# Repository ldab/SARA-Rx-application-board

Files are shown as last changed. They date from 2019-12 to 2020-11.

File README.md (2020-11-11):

# SARA-Rx application board

 SARA-R4 NB-IoT + Cat-M1 + GNSS application board - NINA-B3 with Secure MQTT






# **:heavy_exclamation_mark:BEFORE YOU DO ANYTHING, CHECK BATTERY POLARITY:heavy_exclamation_mark:**

## TODO

- [ ] More details about battery etc...
- [ ] !!! Better Socket close URC handler.
- [ ] Check AT response based on the last chars, in order to avoid missing URCs when after "OK" for example
- [ ] Implement Subscribe;

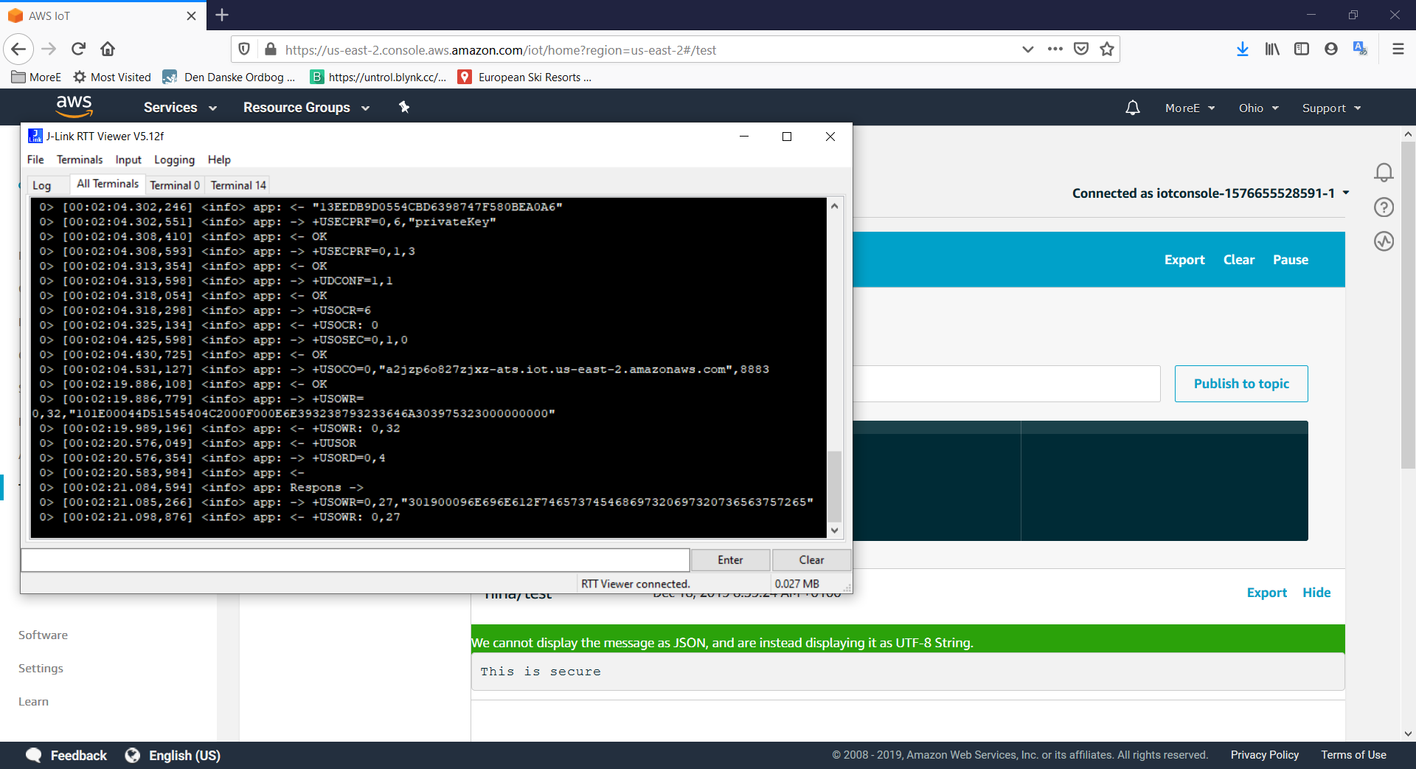
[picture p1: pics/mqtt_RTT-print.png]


## Energy Budget

* 88mA active current;
* Code takes ~10 seconds to execute;
* Wakes every hour;
* 40uA Sleep current;
* 10 hours of light available;
* V charge ready = 3.67V;
* V Over discharge = 3.6V;
* V Over charge = 4.12V;

**Source Power Required = 3.8mW**

**Storage Required = 4.73mAh**

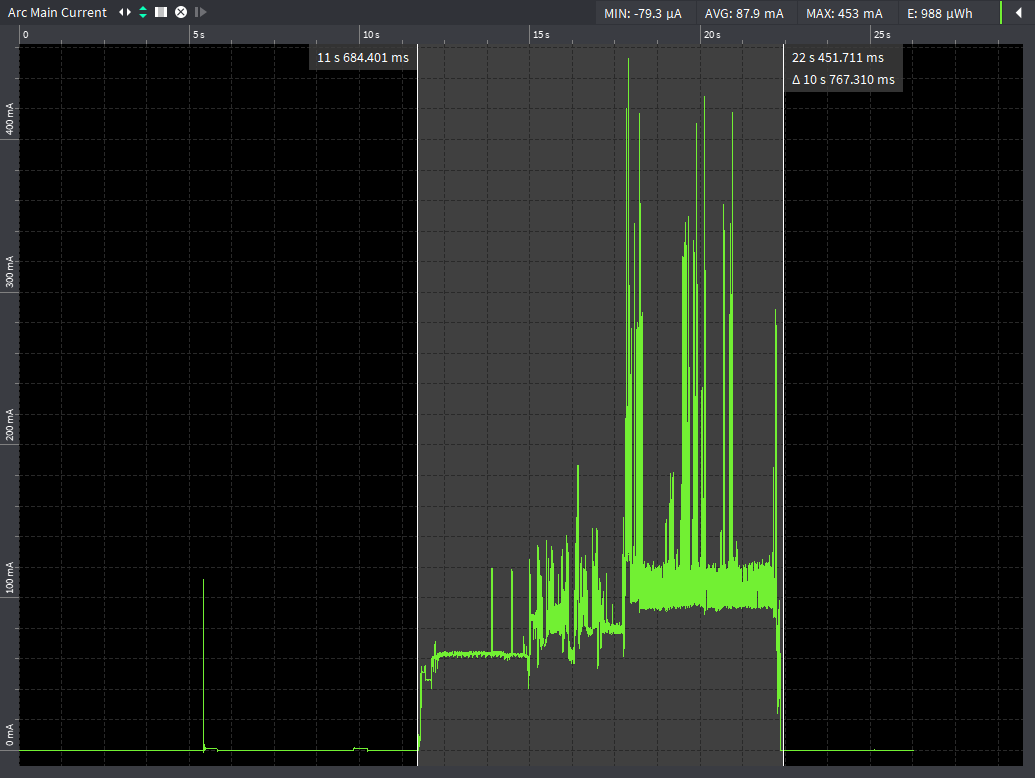
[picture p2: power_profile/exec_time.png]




### Sleep Current

| Component 	| Current 	|
|---	|---	|
| SARA-R410 	| 7uA 	|
| NINA-B3 	| 3uA 	|
| Batt ADC  	| 3uA 	|
| SHTC3 	| 0.5uA 	|
| TP4054 	| 1uA 	|
| TXS0108 	| 5uA(?)  	|
| TPS61021A  	| 17uA 	  |
| TOTAL 	| ~37uA 	|

## Nordic SDK

* This is based on nRF5_SDK_16.0.0_98a08e2, get yours here: https://www.nordicsemi.com/Software-and-tools/Software/nRF5-SDK/Download



1. Sign in to the AWS IoT Console
2. Register a Device in the Registry
3. Configure Your Device
4. View Device MQTT Messages with the AWS IoT MQTT Client

https://docs.aws.amazon.com/iot/latest/developerguide/iot-gs.html

* 120mA active current;
* Code takes 15 seconds to execute;
* Wakes every hour;
* 2mA Sleep current *This needs to be optimized*;
* 10 hours of light available;
* V charge ready = 3.67V;
* V Over discharge = 3.6V;
* V Over charge = 4.12V;

1. Clone this repo to a local folder ```> git clone https://github.com/ldab/SARA-Rx-application-board```
2. Point the `$(SDK)` @`./code/ninab3/blank/ses/libuarte_pca10056.emProject` to where you have installed Nordic SDK, for example `C:\nRF\nRF5_SDK_16.0.0_98a08e2`
3. Like so: `macros="CMSIS_CONFIG_TOOL=C:/nRF/nRF5_SDK_16.0.0_98a08e2/external_tools/cmsisconfig/CMSIS_Configuration_Wizard.jar;SDK=C:/nRF/nRF5_SDK_16.0.0_98a08e2"`
4. Open the SEGGER Embedded Studio project file located in `./code/ninab3/blank/ses/libuarte_pca10056.emProject`

* PS. don't forget to set the NFC Pins as GPIO on the Preprocessor: `CONFIG_NFCT_PINS_AS_GPIOS`

Ref. https://devzone.nordicsemi.com/f/nordic-q-a/44638/how-to-move-an-sdk-example-out-of-the-sdk-tree

## IoT Dashboard

* Adafruit https://io.adafruit.com provides a free MQTT broker with a Dashboard allowing this project to be displayed publicly with little to no effort
  * Create an account and insert your KEY as the `MQTT_PASS`
  * `MQTT_USER` is the username used for creating the account.

* Adafruit expect data as a json, for example:

    ```
    sprintf(_msg, "{\"feeds\": {\"T\": %.01f,\"H\": %.01f,\"Bpc\": %d,\"RSRP\": %.02f,\"Bv\": %.02f}}",
            temperature, humidity, batt_lvl_in_percentage, modemInfo.RSRP, _b)
    ```

* The topic, groups and feeds are created automagically, on the example the MAC address is added as an identifier:

    ```
    sprintf(topic, "lbispo/g/nina_%X/json", NRF_FICR->DEVICEADDR[0]);
    ```

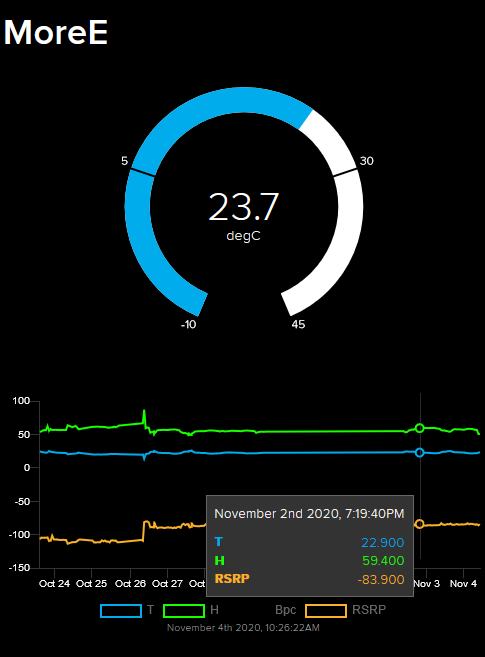
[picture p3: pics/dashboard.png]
 

https://io.adafruit.com/lbispo/dashboards/moree?kiosk=true

## Efficiency

 

## Schematic

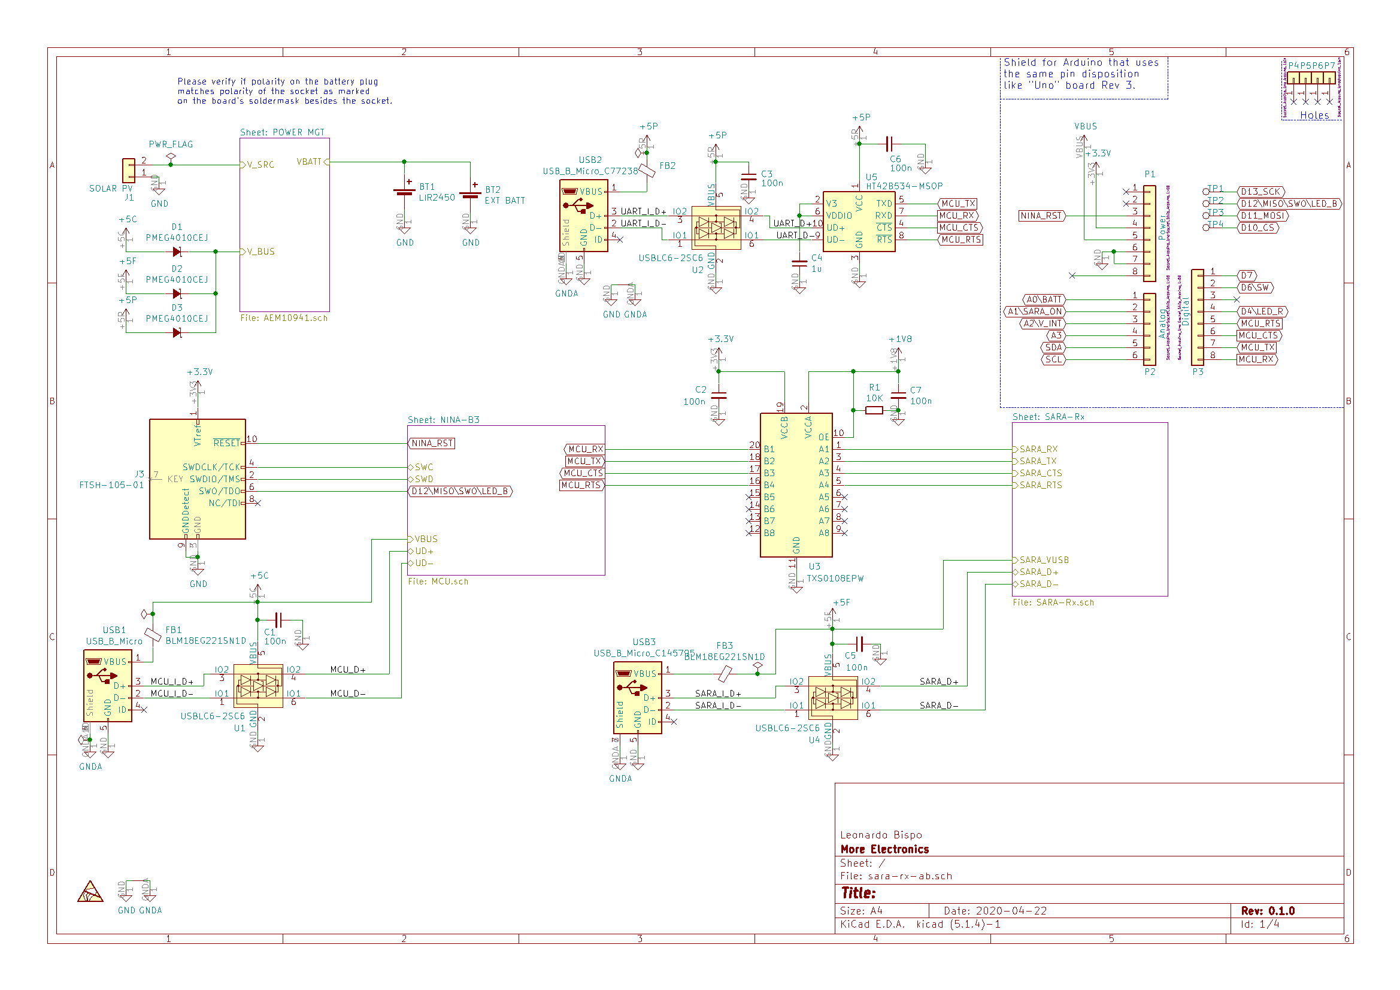
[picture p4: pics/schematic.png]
Board Schematic


## PCB

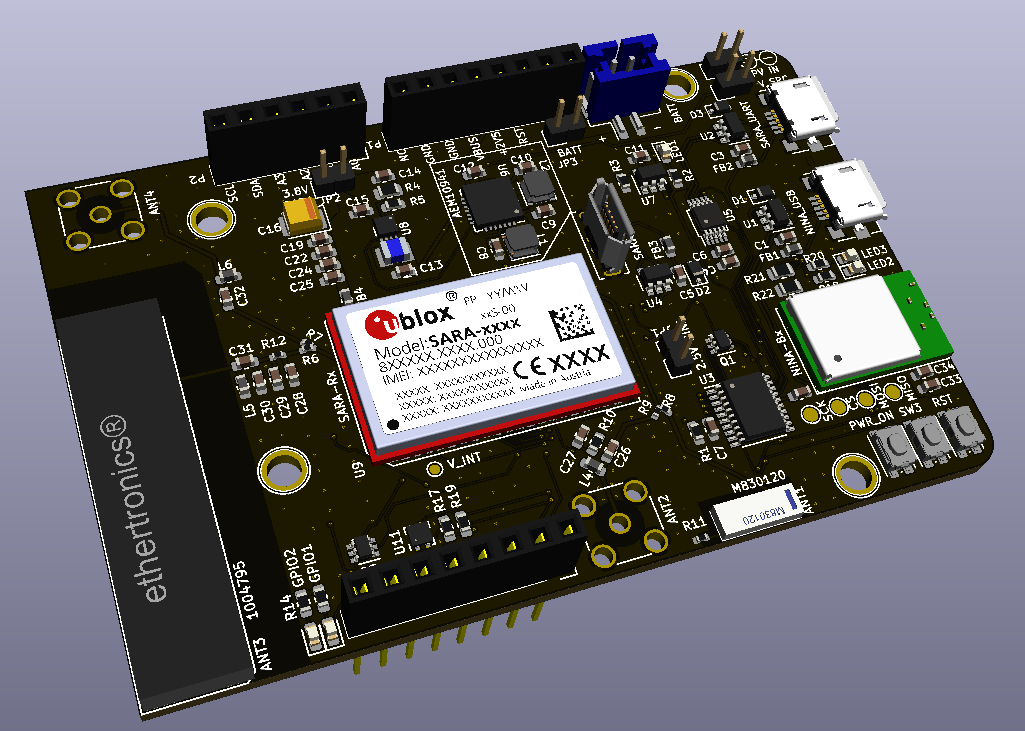
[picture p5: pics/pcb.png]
3D PCB
 

## BOM

Board BOM

## Enclosure

3D 

## Kown issues, limintations

* MQTT Socket Implementaition can only **publish** QoS 0 messages.

## Thoughts or Improvements

* Use STATUS 2 of AEM10941 as last grasp;
* Control boost converter EN, in order to turn SARA Off;
  * Remove boost converter, as it does not boost a lot since Vbatt ON = 3.6V.
* SARA RESET Pin access;
* Use 101b AEM10941 Configuration in order to Vovdis = 3.0V givin extra ~20% battery (?).
* Open Drain 74LVC3G07 buffer on NINA LED, in order to avoid leakage.

## Credits

* [MQTTBox](http://workswithweb.com/mqttbox.html) for Windows in order to communicate with the broker and check messages;
* [CloudMQTT](https://www.cloudmqtt.com/) Free Cloud Broker;
* MQTT implementation inspired and based on [knolleary PubSub Client](https://github.com/knolleary/pubsubclient);
* AT Commands implementation inspired on [vshymanskyy TinyGSM](https://github.com/vshymanskyy/TinyGSM);
* GitHub Shields and Badges created with [Shields.io](https://github.com/badges/shields/);

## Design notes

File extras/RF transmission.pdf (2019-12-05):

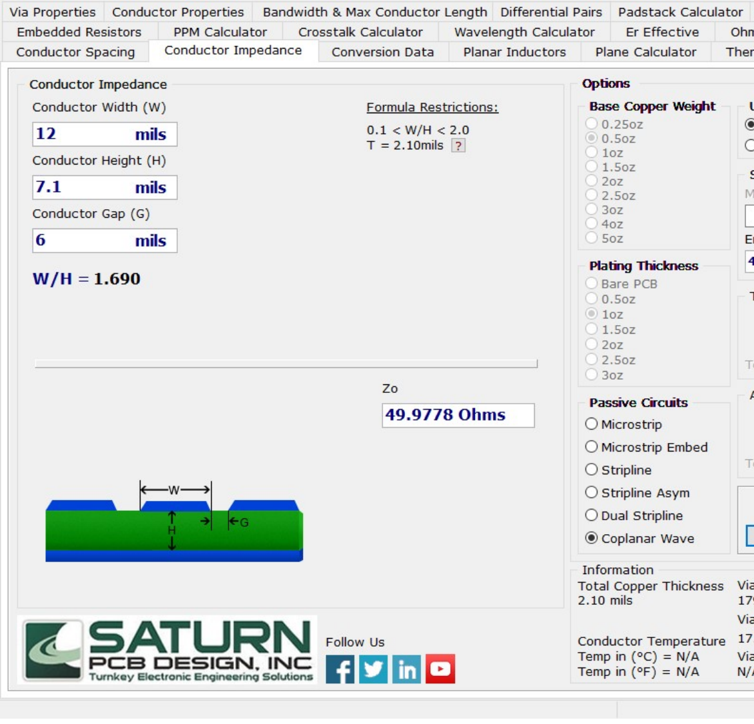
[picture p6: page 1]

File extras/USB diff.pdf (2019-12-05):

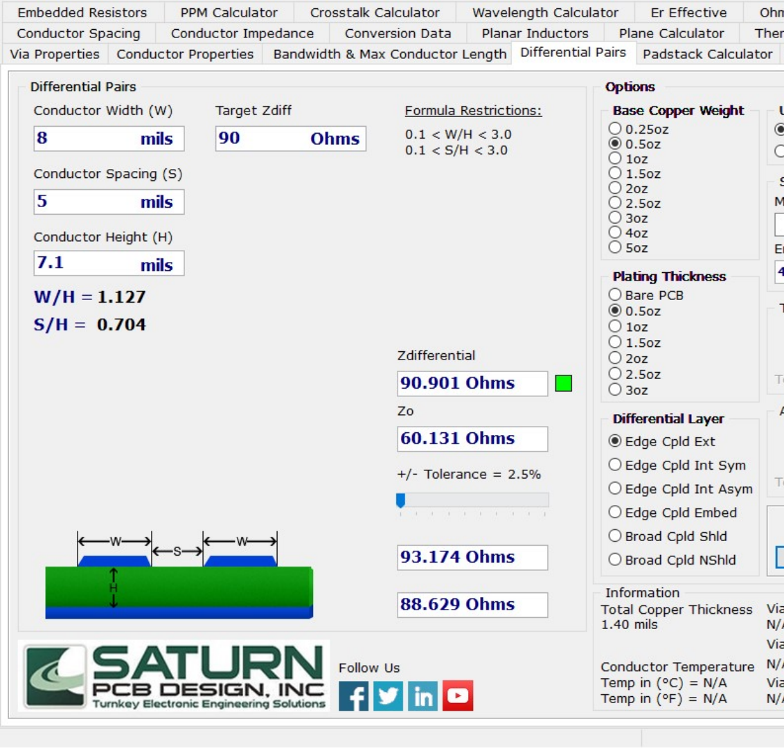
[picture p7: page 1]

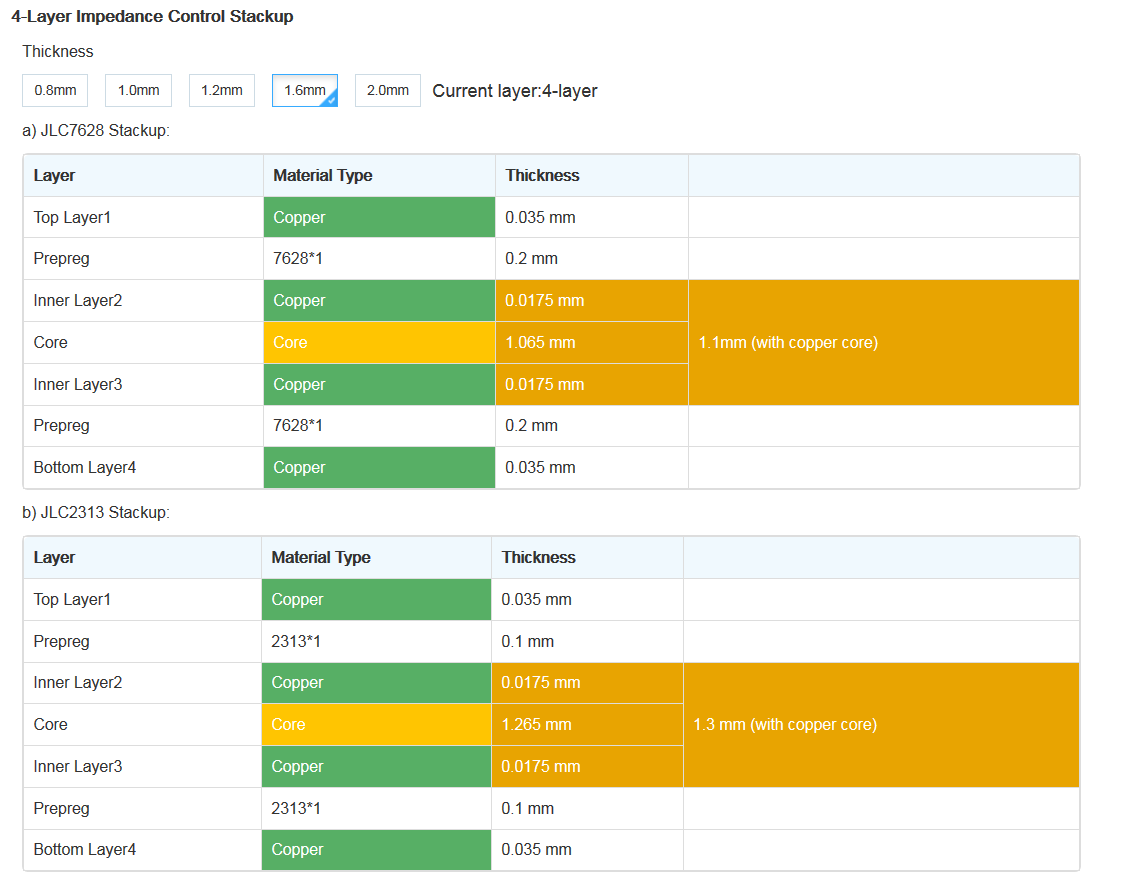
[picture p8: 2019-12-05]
PCB/PCB Stackup.png

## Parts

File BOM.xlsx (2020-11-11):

 | Quantity | Manufacture Part Number | Manufacturer(optional) | Description(optional) | LCSC Part Number(optional) | Package(optional)
ANT2 | 1 |  |  | Conn_Coaxial | C411575 | Connector_Coaxial:SMA_Amphenol_132291_Vertical
BT1 | 1 |  |  | LIR2450 | C238100 | Battery:BatteryHolder_Keystone_3008_1x2450
BT2 | 1 | B2B-PH-SM4-TB(LF)(SN) |  | EXT BATT | C160352 | Connector_JST:JST_PH_B2B-PH-SM4-TB_1x02-1MP_P2.00mm_Vertical
> C1-C3, C5-C7, C19, C23, C33, C34 | 10 | C1608X7R1E104KT000N |  | 100n | C338036 | Capacitor_SMD:C_0603_1608Metric
C4 | 1 | EMK107B7105KA-T |  | 1u | C92759 | Capacitor_SMD:C_0603_1608Metric
> C8-C13, C15 | 7 | JMK107BJ106MA-T |  | 10u | C87152 | Capacitor_SMD:C_0603_1608Metric
> C14, C31 | 2 | CC0603CRNPO9BN4R7 |  | 4.7p | C282071 | Capacitor_SMD:C_0603_1608Metric
C16 | 1 |  |  | 100u | C16133 | Capacitor_Tantalum_SMD:CP_EIA-3528-21_Kemet-B
> C17, C18, C20, C21, C26 | 5 | CC0603JRNPO9BN470 |  | 47p | C1671 | Capacitor_SMD:C_0603_1608Metric | replaced
C25 | 1 | GRM1885C2A680JA01D |  | 68p | C162261 | Capacitor_SMD:C_0603_1608Metric
> C22, C27 | 2 | CC0603KRX7R0BB103 |  | 10n | C107059 | Capacitor_SMD:C_0603_1608Metric
C28 | 1 | GRM1885C1H5R0BA01D |  | 5p | C162236 | Capacitor_SMD:C_0603_1608Metric
C30 | 1 | CL10C0R3CB8NNNC |  | 0.3p | C170140 | Capacitor_SMD:C_0603_1608Metric
> C24, C32 | 2 | CGA3E2C0G1H150JT0Y0N |  | 15p | C342889 | Capacitor_SMD:C_0603_1608Metric
> D1-D3 | 3 | PMEG4010CEJ |  | PMEG4010CEJ | C50704 | Diode_SMD:D_SOD-323F
> D4, D5 | 2 | PESD5V0U2BT |  | PESD5V0U2BT | C85399 | Package_TO_SOT_SMD:SOT-23
> FB1-FB4 | 4 | BLM18EG221SN1D |  | BLM18EG221SN1D | C17305 | Inductor_SMD:L_0603_1608Metric | replaced
J3 | 1 | 20021221-00010C4LF |  | FTSH-105-01 | C180221 | custom:SWD_JTAG
J5 | 1 | SMO-1512 |  | SMO-1512 | C125621 | SMO1512
 | 4 | C5664 |  | Jumper Shunt | C5664
> JP1-JP4 | 4 | MTP220-1102S1 |  | Jumper_NC_Small | C376075 | Connector_PinHeader_2.00mm:PinHeader_1x02_P2.00mm_Vertical
> L1, L2 | 2 | NRH3010T100MNV |  | 10u | C223113 | SamacSys_Parts:L_Taiyo-Yuden_NRH30xx
L3 | 1 | DFE252012P-R47M=P2 |  | DFE252012P-R47M=P2 | C237552 | INDC2520X120N
L4 | 1 | HK160827NJ-T |  | 27n | C222672 | Inductor_SMD:L_0603_1608Metric
L5 | 1 | VHF160808H8N2ST |  | 8.2n | C139273 | Inductor_SMD:L_0603_1608Metric
L6 | 1 | LQG18HN39NJ00D |  | 39n | C86134 | Inductor_SMD:L_0603_1608Metric | replaced
> LED1, LED2 | 2 | 19-217/R6C-AL1M2VY/3T |  | 19-217/R6C-AL1M2VY/3T | C72044 | LED_SMD:LED_0603_1608Metric
LED3 | 3 | LTST-C191KGKT |  | LTST-C191KGKT | C125098 | LED_SMD:LED_0603_1608Metric
> Q1, Q2 | 2 | MUN5214DW1T1G |  | MUN5214DW1T1G | C94403 | Package_TO_SOT_SMD:SOT-363_SC-70-6
> R1, R2, R17, R19,R3,R23 | 6 | 0603WAJ0103T5E |  | 10K | C15401 | Resistor_SMD:R_0603_1608Metric
> R4, R21, R22 | 3 | WF08H1004BTL |  | 1M±0.1% | C384461 | Resistor_SMD:R_0805_2012Metric
R5 | 1 | RC0603FR-07267KL |  | 267K | C185347 | Resistor_SMD:R_0603_1608Metric
R10 | 1 | 0603WAJ0100T5E |  | 10 | C25202 | Resistor_SMD:R_0603_1608Metric
> R6, R8, R11, R12, R15, R16 | 6 | 0402WGF0000TCE |  | 0R | C17168 | Resistor_SMD:R_0402_1005Metric
> R13, R14, R18, R20 | 4 | 0603WAJ0102T5E |  | 1K | C25585 | Resistor_SMD:R_0603_1608Metric
SW1 | 3 | K2-1809SN-D4DW-06 |  | PWR_ON | C128941 | SamacSys_Parts:SW_Push_1P1T_NO_CK_KMR2
U3 | 1 | TXS0108EPWR |  | TXS0108EPWR | C17206 | Package_SO:SSOP-20_4.4x6.5mm_P0.65mm
> U1, U2, U4 | 3 | USBLC6-2SC6 |  | USBLC6-2SC6 | C7519 | Package_TO_SOT_SMD:SOT-23-6
U5 | 1 | HT42B534 |  | HT42B534-MSOP | C95344 | Package_SO:MSOP-10_3x3mm_P0.5mm
U7 | 1 | TP4054 |  | TP4054 | C32574 | Package_TO_SOT_SMD:SOT-23-5
U8 | 1 | TPS61021A |  | TPS61021A | C193037 | Package_SON:WSON-8-1EP_2x2mm_P0.5mm_EP0.9x1.6mm_ThermalVias
U11 | 1 | SHTC3 |  | Temperature & Humidity Sensors | C194656 | Package_DFN_QFN:AMS_QFN-4-1EP_2x2mm_P0.95mm_EP0.7x1.6mm
USB1, USB2 | 2 | U-F-M5SS-W-1 |  | USB_B_Micro | C77238 | SamacSys_Parts:C77238
USB3 | 1 | U-D-M5DD-W-1 |  | USB_B_Micro_C145795 | C145795 | custom:USB_Micro-B_U-D-M5DD-W-1_VERTICAL

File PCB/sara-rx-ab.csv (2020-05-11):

Source: | D:\untrol.io\10. Open Source\SARA-Rx-application-board\PCB\sara-rx-ab.sch
Date: | 01/22/20 14:25:27
Tool: | Eeschema (5.1.4)-1
Generator: | C:\Program Files\KiCad\bin\scripting\plugins/bom_csv_grouped_by_value_with_fp.py
Component Count: | 123
Ref | Qnty | Value | Cmp name | Footprint | Description | Vendor
ANT1, | 1 | M830120 | antennaM830120 | custom:M830120 | Universal Broadband FR4 Embedded LTE / LPWA Antenna
ANT2, | 1 | Conn_Coaxial | Conn_Coaxial | Connector_Coaxial:SMA_Amphenol_132291_Vertical | coaxial connector (BNC, SMA, SMB, SMC, Cinch/RCA, ...)
ANT3, | 1 | PCB ANT 1004795 | antenna1004795 | custom:1009475 | Universal Broadband FR4 Embedded LTE / LPWA Antenna
ANT4, | 1 | EXT Antenna | Conn_Coaxial | Connector_Coaxial:SMA_Amphenol_132291_Vertical | coaxial connector (BNC, SMA, SMB, SMC, Cinch/RCA, ...)
BT1, | 1 | LIR2450 | Battery_Cell | Battery:BatteryHolder_Keystone_3008_1x2450 | Single-cell battery
BT2, | 1 | EXT BATT | Battery_Cell | Connector_JST:JST_PH_B2B-PH-SM4-TB_1x02-1MP_P2.00mm_Vertical | Single-cell battery
C2, C7, C1, C3, C6, C5, C23, C19, C34, C33, | 10 | 100n | C_Small | Capacitor_SMD:C_0603_1608Metric | Unpolarized capacitor, small symbol
C4, | 1 | 1u | C_Small | Capacitor_SMD:C_0603_1608Metric | Unpolarized capacitor, small symbol
C10, C9, C8, C12, C11, C13, C15, | 7 | 10u | C_Small | Capacitor_SMD:C_0603_1608Metric | Unpolarized capacitor, small symbol
C14, C31, | 2 | 4.7p | C_Small | Capacitor_SMD:C_0603_1608Metric | Unpolarized capacitor, small symbol
C16, | 1 | 100u | CP_Small | Capacitor_Tantalum_SMD:CP_EIA-3528-21_Kemet-B | Polarized capacitor, small symbol
C21, C20, C18, C17, C26, | 5 | 47p | C_Small | Capacitor_SMD:C_0603_1608Metric | Unpolarized capacitor, small symbol
C25, | 1 | 68p | C_Small | Capacitor_SMD:C_0603_1608Metric | Unpolarized capacitor, small symbol
C27, C22, | 2 | 10n | C_Small | Capacitor_SMD:C_0603_1608Metric | Unpolarized capacitor, small symbol
C28, | 1 | 5p | C_Small | Capacitor_SMD:C_0603_1608Metric | Unpolarized capacitor, small symbol
C29, | 1 | DNP | C_Small | Capacitor_SMD:C_0603_1608Metric | Unpolarized capacitor, small symbol
C30, | 1 | 0.3p | C_Small | Capacitor_SMD:C_0603_1608Metric | Unpolarized capacitor, small symbol
C32, C24, | 2 | 15p | C_Small | Capacitor_SMD:C_0603_1608Metric | Unpolarized capacitor, small symbol
D1, D2, D3, | 3 | PMEG4010CEJ | D_Schottky_Small_ALT | Diode_SMD:D_SOD-323F | Schottky diode, small symbol, filled shape
D5, D4, | 2 | PESD5V0U2BT | PESD5V0U2BT | Package_TO_SOT_SMD:SOT-23 | Ultra low capacitance bidirectional double ESD protection diode
FB3, FB1, FB2, FB4, | 4 | BLM18EG221SN1D | Ferrite_Bead_Small | Inductor_SMD:L_0603_1608Metric | Ferrite bead, small symbol
GPIO1, GPIO2, LED3, | 3 | LTST-C191KGKT | LED_Small_ALT | LED_SMD:LED_0603_1608Metric | Light emitting diode, small symbol, filled shape
J1, | 1 | SOLAR PV | Conn_01x02 | Connector_PinHeader_2.00mm:PinHeader_1x02_P2.00mm_Vertical | Generic connector, single row, 01x02, script generated (kicad-library-utils/schlib/autogen/connector/)
J2, J4, | 2 | Bridge | Bridge | custom:4Layer_15mil
J3, | 1 | FTSH-105-01 | Conn_ARM_JTAG_SWD_10 | custom:SWD_JTAG | Cortex Debug Connector, standard ARM Cortex-M SWD and JTAG interface
J5, | 1 | SMO-1512 | SMO-1512 | SMO1512 | Connector - Card Sockets SMD RoHS
J6, | 1 | Bridge | Bridge | custom:4Layer_square
JP1, JP2, JP3, JP4, | 4 | Jumper_NC_Small | Jumper_NC_Small | Connector_PinHeader_2.00mm:PinHeader_1x02_P2.00mm_Vertical | Jumper, normally closed, small symbol
L1, L2, | 2 | 10u | L_Small | SamacSys_Parts:L_Taiyo-Yuden_NRH30xx | Inductor, small symbol
L3, | 1 | DFE252012P-R47M=P2 | DFE252012P-R47M=P2 | INDC2520X120N | Toko DFE252012P Series Shielded Wire-wound SMD Inductor with a Powered Iron Core, 470 nH Wire-Wound 6.4A Idc
L4, | 1 | 27n | L_Small | Inductor_SMD:L_0603_1608Metric | Inductor, small symbol
L5, | 1 | 8.2n | L_Small | Inductor_SMD:L_0603_1608Metric | Inductor, small symbol
L6, | 1 | 39n | L_Small | Inductor_SMD:L_0603_1608Metric | Inductor, small symbol
LED1, LED2, | 2 | 19-217/R6C-AL1M2VY/3T | LED_Small_ALT | LED_SMD:LED_0603_1608Metric | Light emitting diode, small symbol, filled shape
P1, | 1 | Power | Conn_01x08 | Socket_Arduino_Uno:Socket_Strip_Arduino_1x08 | Generic connector, single row, 01x08, script generated (kicad-library-utils/schlib/autogen/connector/)
P2, | 1 | Analog | Conn_01x06 | Socket_Arduino_Uno:Socket_Strip_Arduino_1x06 | Generic connector, single row, 01x06, script generated (kicad-library-utils/schlib/autogen/connector/)
P3, | 1 | Digital | Conn_01x08 | Socket_Arduino_Uno:Socket_Strip_Arduino_1x08 | Generic connector, single row, 01x08, script generated (kicad-library-utils/schlib/autogen/connector/)
P4, P5, P6, P7, | 4 | CONN_01X01 | Conn_01x01 | Socket_Arduino_Uno:Arduino_1pin | Generic connector, single row, 01x01, script generated (kicad-library-utils/schlib/autogen/connector/)
Q1, Q2, | 2 | MUN5214DW1T1G | Q_DUAL_NPN_NPN_BRT_E1B1C2E2B2C1 | Package_TO_SOT_SMD:SOT-363_SC-70-6 | Dual NPN bias resistor transistor, 6 pin package
R1, R2, R19, R17, | 4 | 10K | R_Small | Resistor_SMD:R_0603_1608Metric | Resistor, small symbol
R3 | 1 | 18K7 | R_Small | Resistor_SMD:R_0603_1608Metric | Resistor, small symbol
R4, R21, R22, | 3 | 1M±0.1% | R_Small | Resistor_SMD:R_0805_2012Metric | Resistor, small symbol
R5, | 1 | 267K | R_Small | Resistor_SMD:R_0603_1608Metric | Resistor, small symbol
R9, R7, | 2 | DNP | R_Small | Resistor_SMD:R_0402_1005Metric | Resistor, small symbol
R10, | 1 | 10 | R_Small | Resistor_SMD:R_0603_1608Metric | Resistor, small symbol
R11, R8, R16, R15, R6, R12, | 6 | 0R | R_Small | Resistor_SMD:R_0402_1005Metric | Resistor, small symbol
R13, R14, R18, R20, | 4 | 1K | R_Small | Resistor_SMD:R_0603_1608Metric | Resistor, small symbol
SW1, | 1 | PWR_ON | SW_Push_KMR2 | SamacSys_Parts:SW_Push_1P1T_NO_CK_KMR2 | Push button switch, generic, two pins
SW2, SW3, | 2 | KMR2 | SW_Push_KMR2 | SamacSys_Parts:SW_Push_1P1T_NO_CK_KMR2 | Push button switch, generic, two pins
TP1, TP2, TP3, TP4, | 4 | TestPoint | TestPoint | TestPoint:TestPoint_Pad_D1.5mm | test point
TP5, | 1 | TestPoint | TestPoint | TestPoint:TestPoint_Pad_D1.0mm | test point
U3, | 1 | TXS0108EPWR | TXB0108DQSR | Package_SO:SSOP-20_4.4x6.5mm_P0.65mm | 8-bit bidirectional voltage level translator with auto-direction sensing USON package
U4, U1, U2, | 3 | USBLC6-2SC6 | USBLC6-2SC6 | Package_TO_SOT_SMD:SOT-23-6 | Bidirectional ESD Protection Diode, SOT-23-6
U5, | 1 | HT42B534-MSOP | HT42B534-MSOP | Package_SO:MSOP-10_3x3mm_P0.5mm | USB serial converter, UART, 10 MSOP-A
U6, | 1 | AEM10941 | AEM10941 | Package_DFN_QFN:QFN-28-1EP_5x5mm_P0.5mm_EP3.35x3.35mm | AEM10941 Highly Efficient, Dual Regulated Output
U7, | 1 | TP4054 | TP4054 | Package_TO_SOT_SMD:SOT-23-5 | Constant-current/constant-voltage linear charger for single cell lithium-ion batteries with 2.9V Trickle Charge, 4.5V to 6.5V VDD, -40 to +85 degree Celcius, TSOT-23-5
U8, | 1 | TPS61021A | TPS61021A | Package_SON:WSON-8-1EP_2x2mm_P0.5mm_EP0.9x1.6mm_ThermalVias | 3-A Boost, Step-up Converter with 0.5-V Ultra Low Input Voltage., WSON-8
U9, | 1 | SARA-Rx | SARA-R511M | RF_GSM:ublox_SARA-G3_LGA-96 | Ublox Multi-band LTE-M / NB-IoT module, GNSS, AT Command Set, LGA-96
U10, | 1 | NINA-B3 | NINA-B3-custom | custom:NINA-B3
U11, | 1 | SHTC3 | SHTC3 | Package_DFN_QFN:AMS_QFN-4-1EP_2x2mm_P0.95mm_EP0.7x1.6mm | Humidity and Temperature Sensor I2C
USB1, | 1 | USB_B_Micro | USB_B_Micro_C77238 | SamacSys_Parts:C77238 | USB Micro Type B connector
USB2, | 1 | USB_B_Micro_C77238 | USB_B_Micro_C77238 | SamacSys_Parts:C77238 | USB Micro Type B connector
USB3, | 1 | USB_B_Micro_C145795 | USB_B_Micro_C145795 | custom:USB_Micro-B_U-D-M5DD-W-1_VERTICAL | USB Micro Type B connector

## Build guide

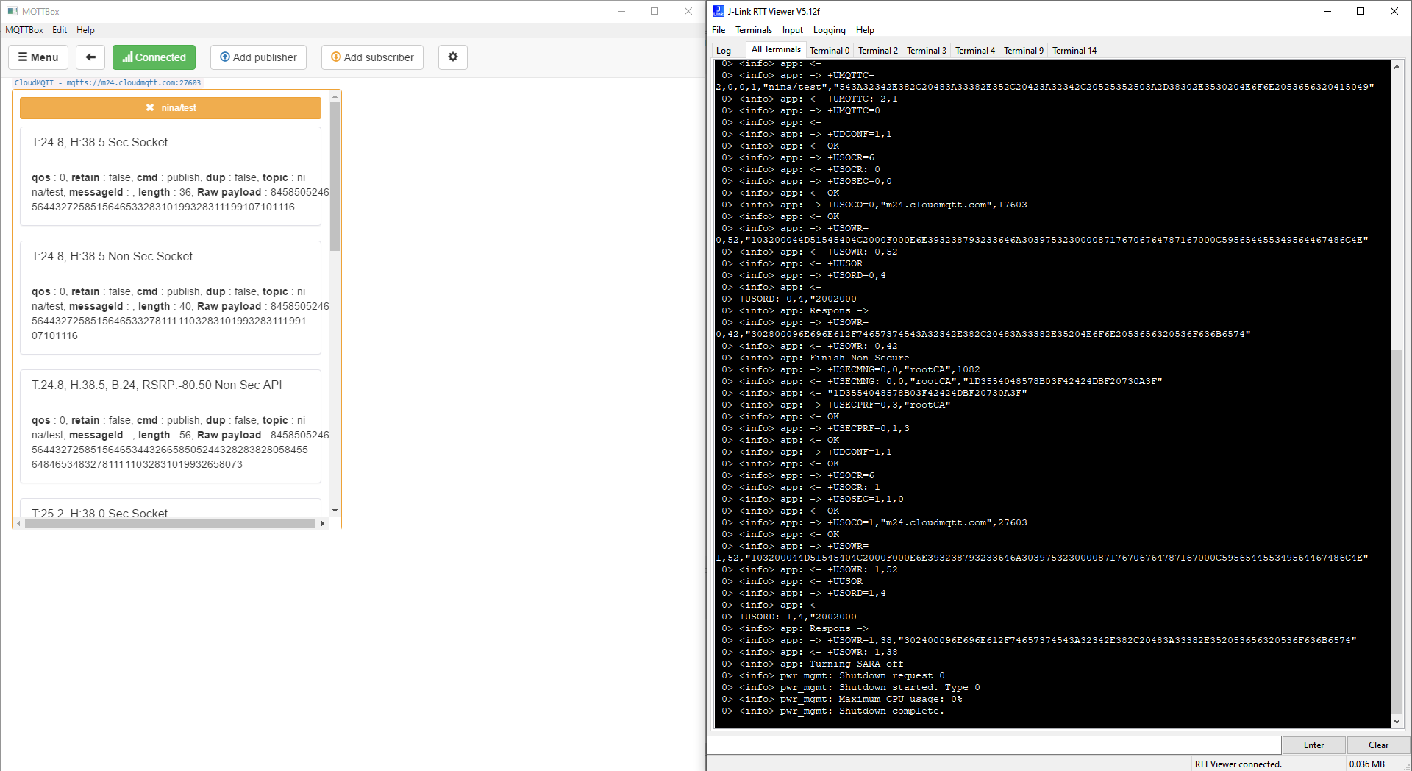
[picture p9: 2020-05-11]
pics/mqtt_RTT-print_2.png

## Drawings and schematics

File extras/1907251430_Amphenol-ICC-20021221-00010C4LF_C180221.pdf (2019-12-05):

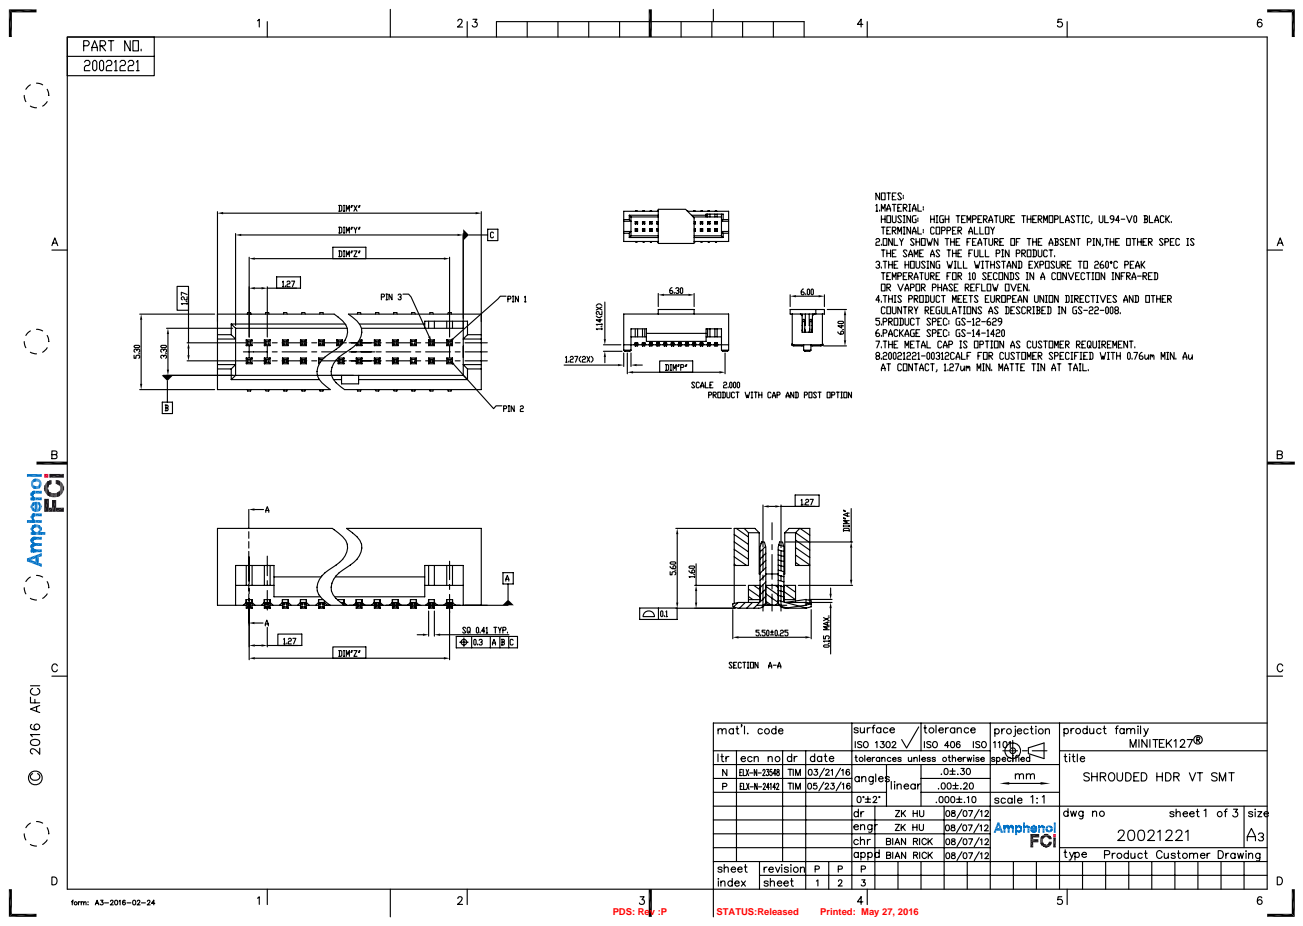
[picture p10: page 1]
PDS: Rev :P; STATUS:Released; Printed: May 27, 2016

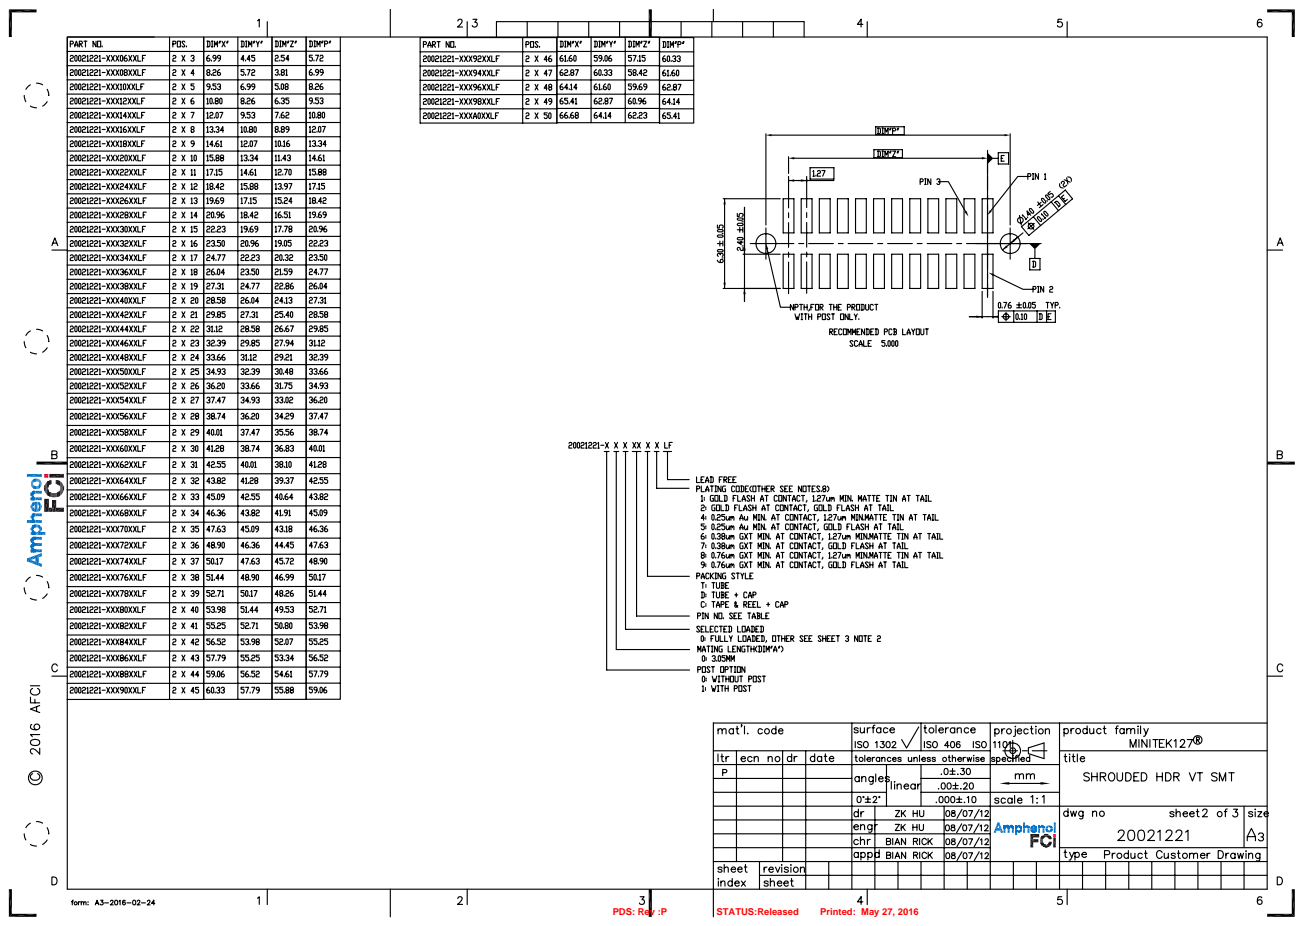
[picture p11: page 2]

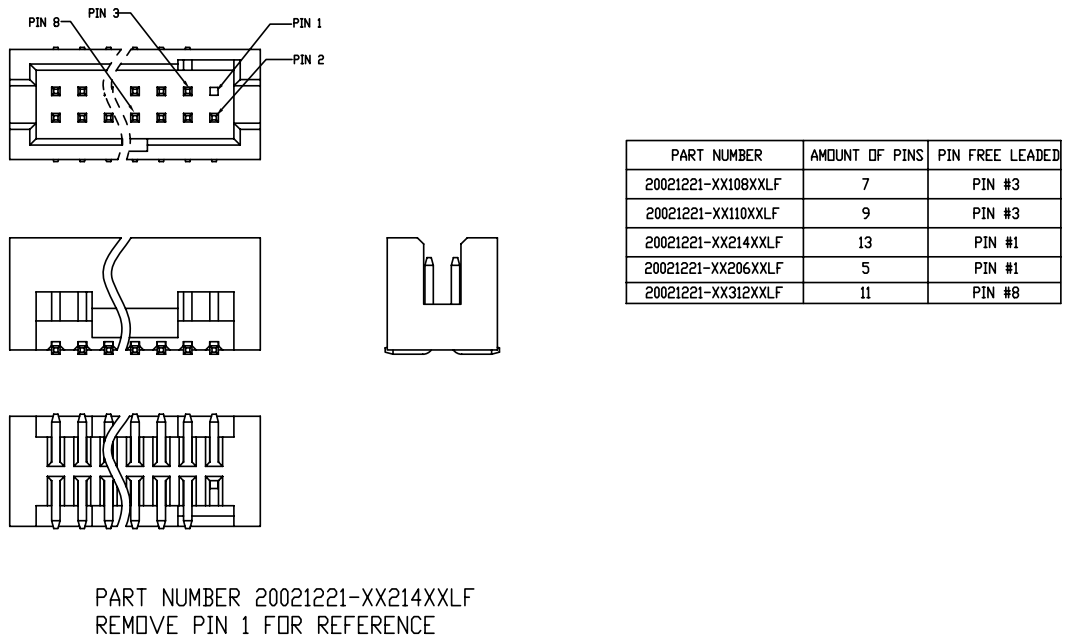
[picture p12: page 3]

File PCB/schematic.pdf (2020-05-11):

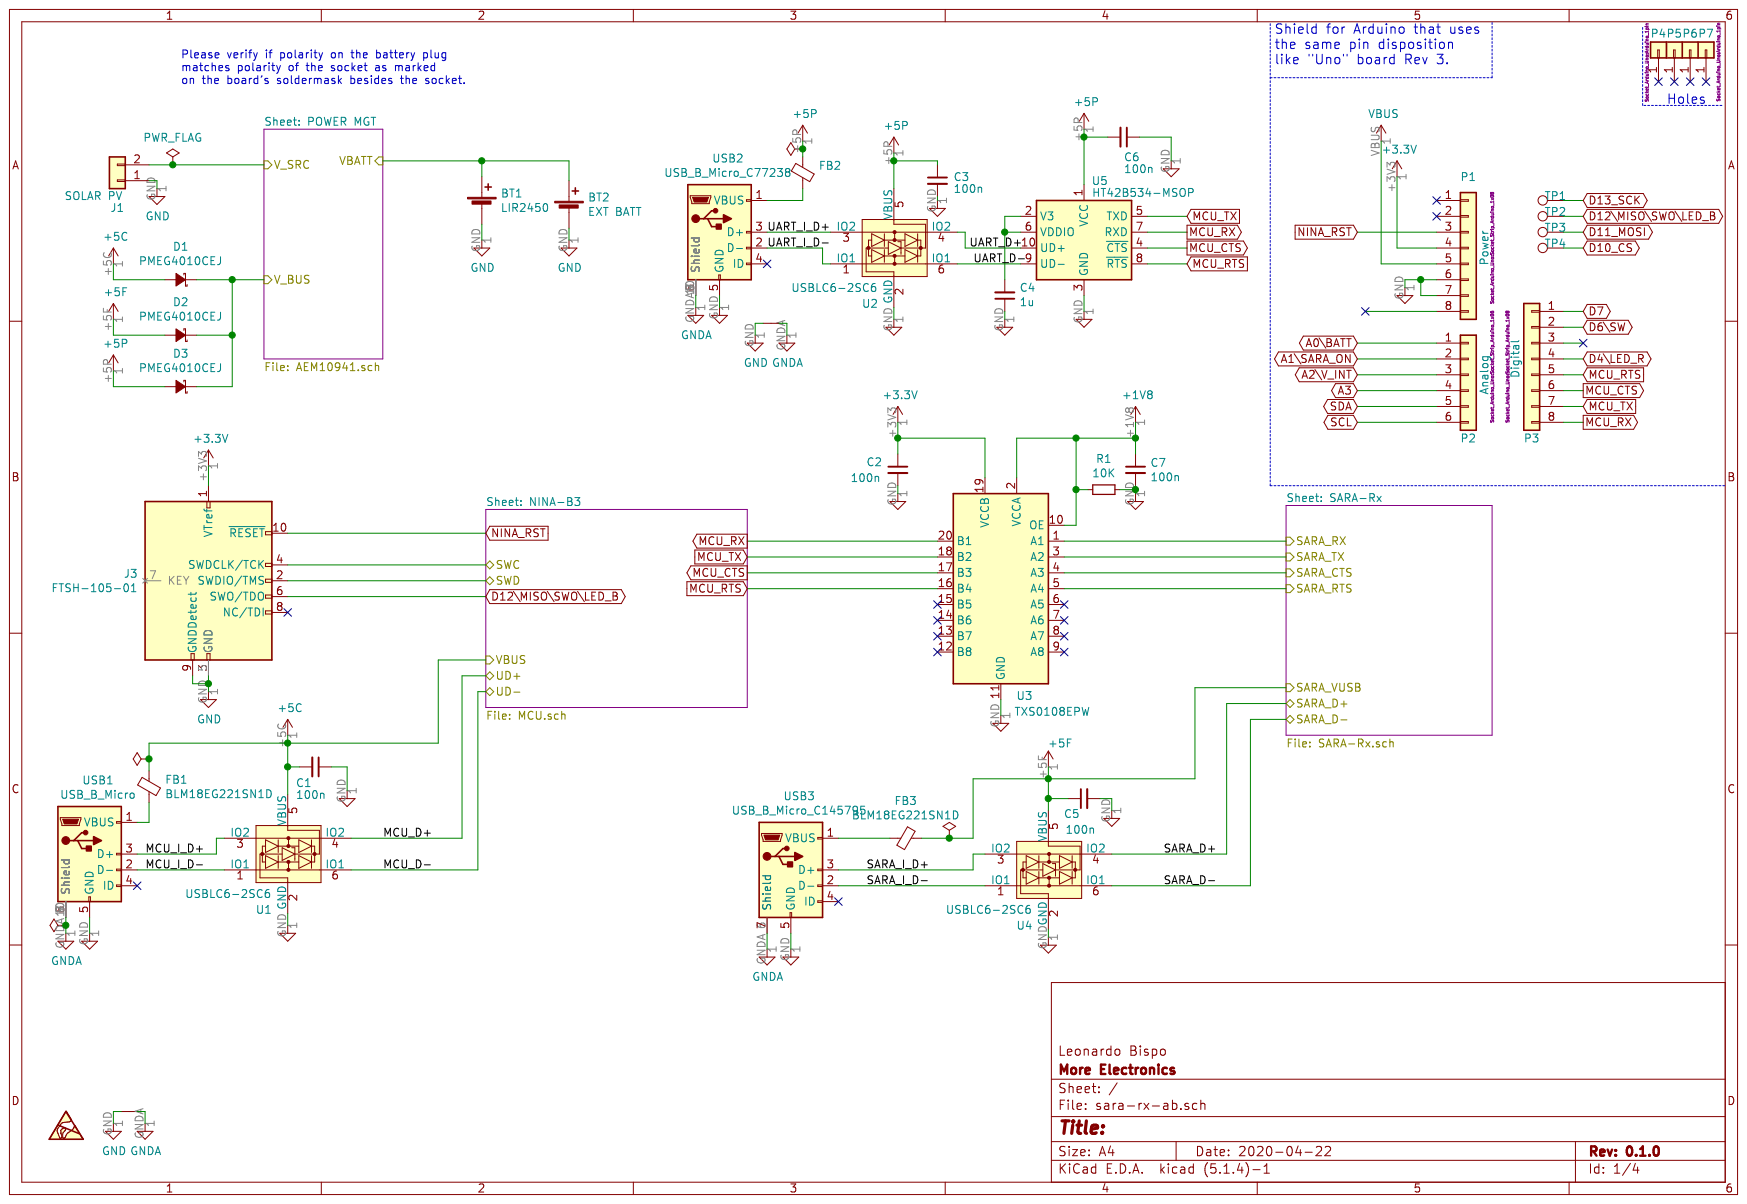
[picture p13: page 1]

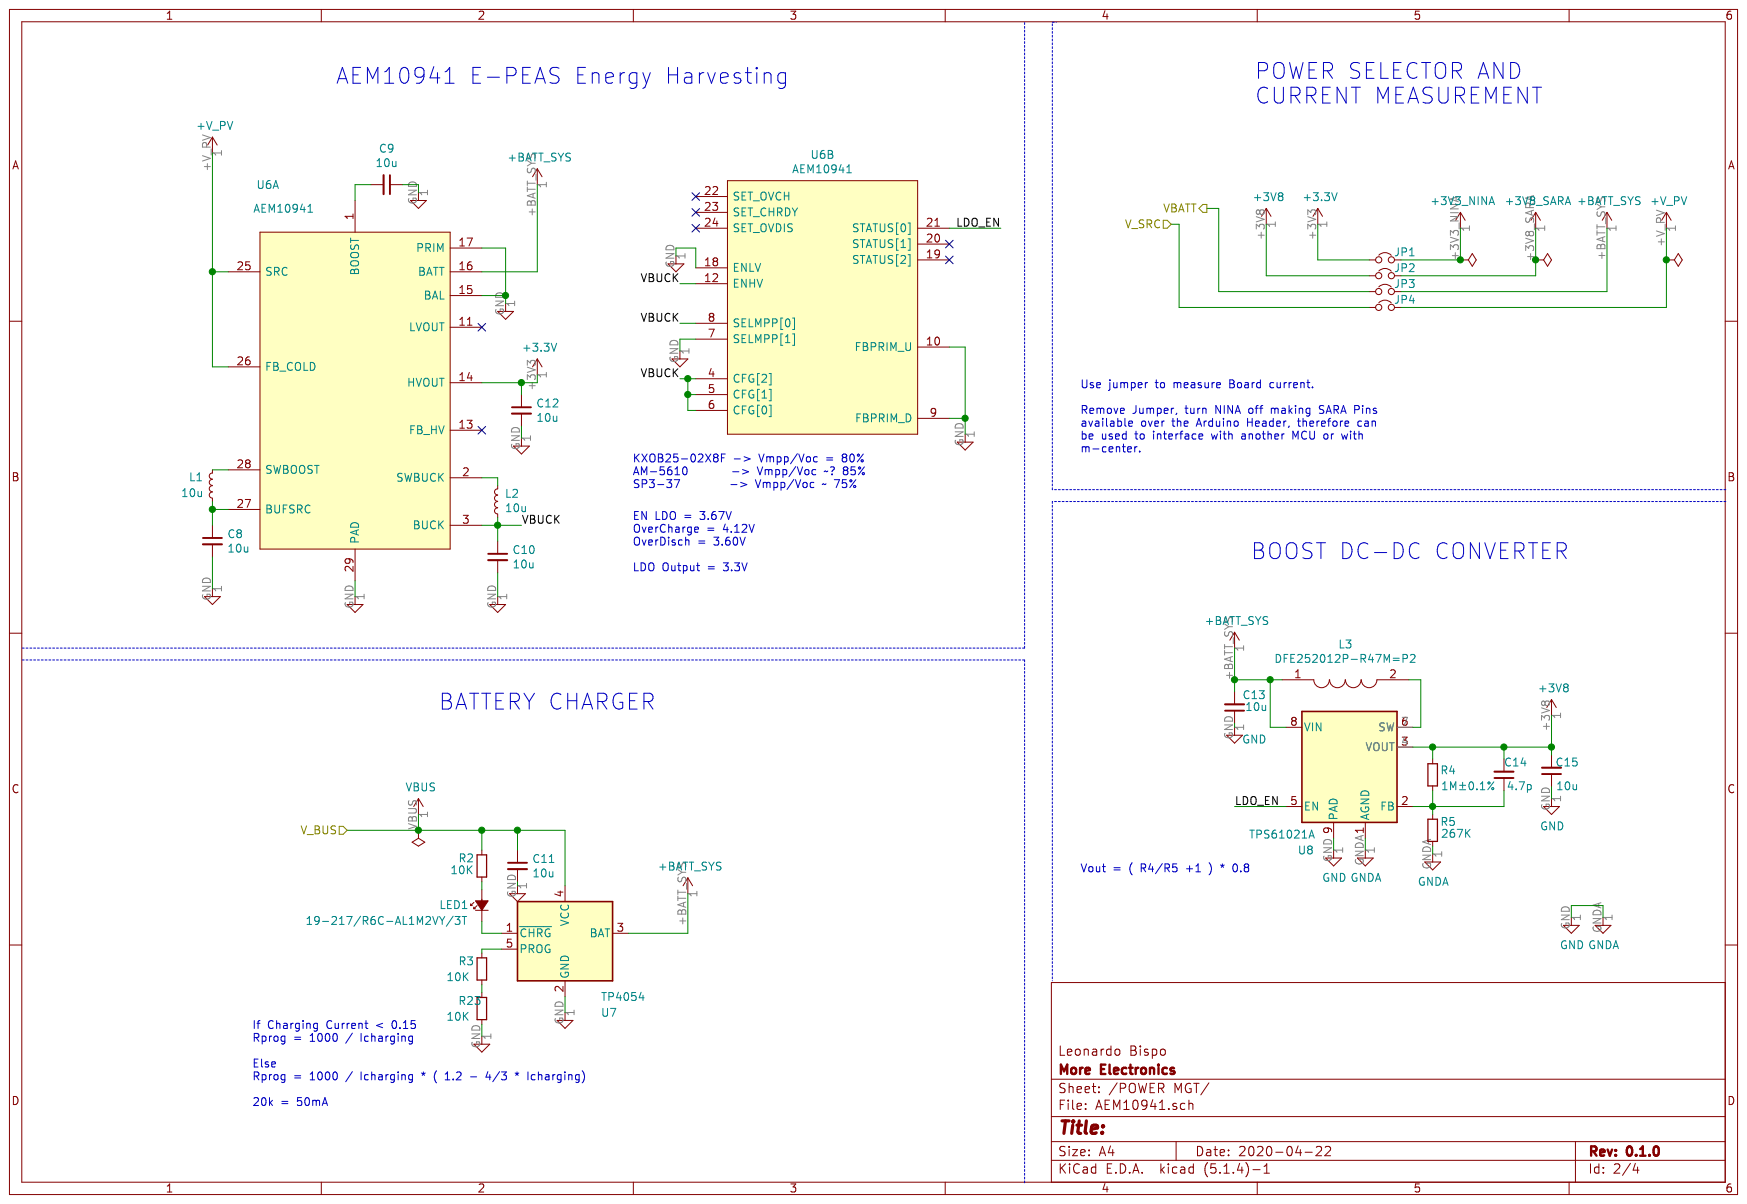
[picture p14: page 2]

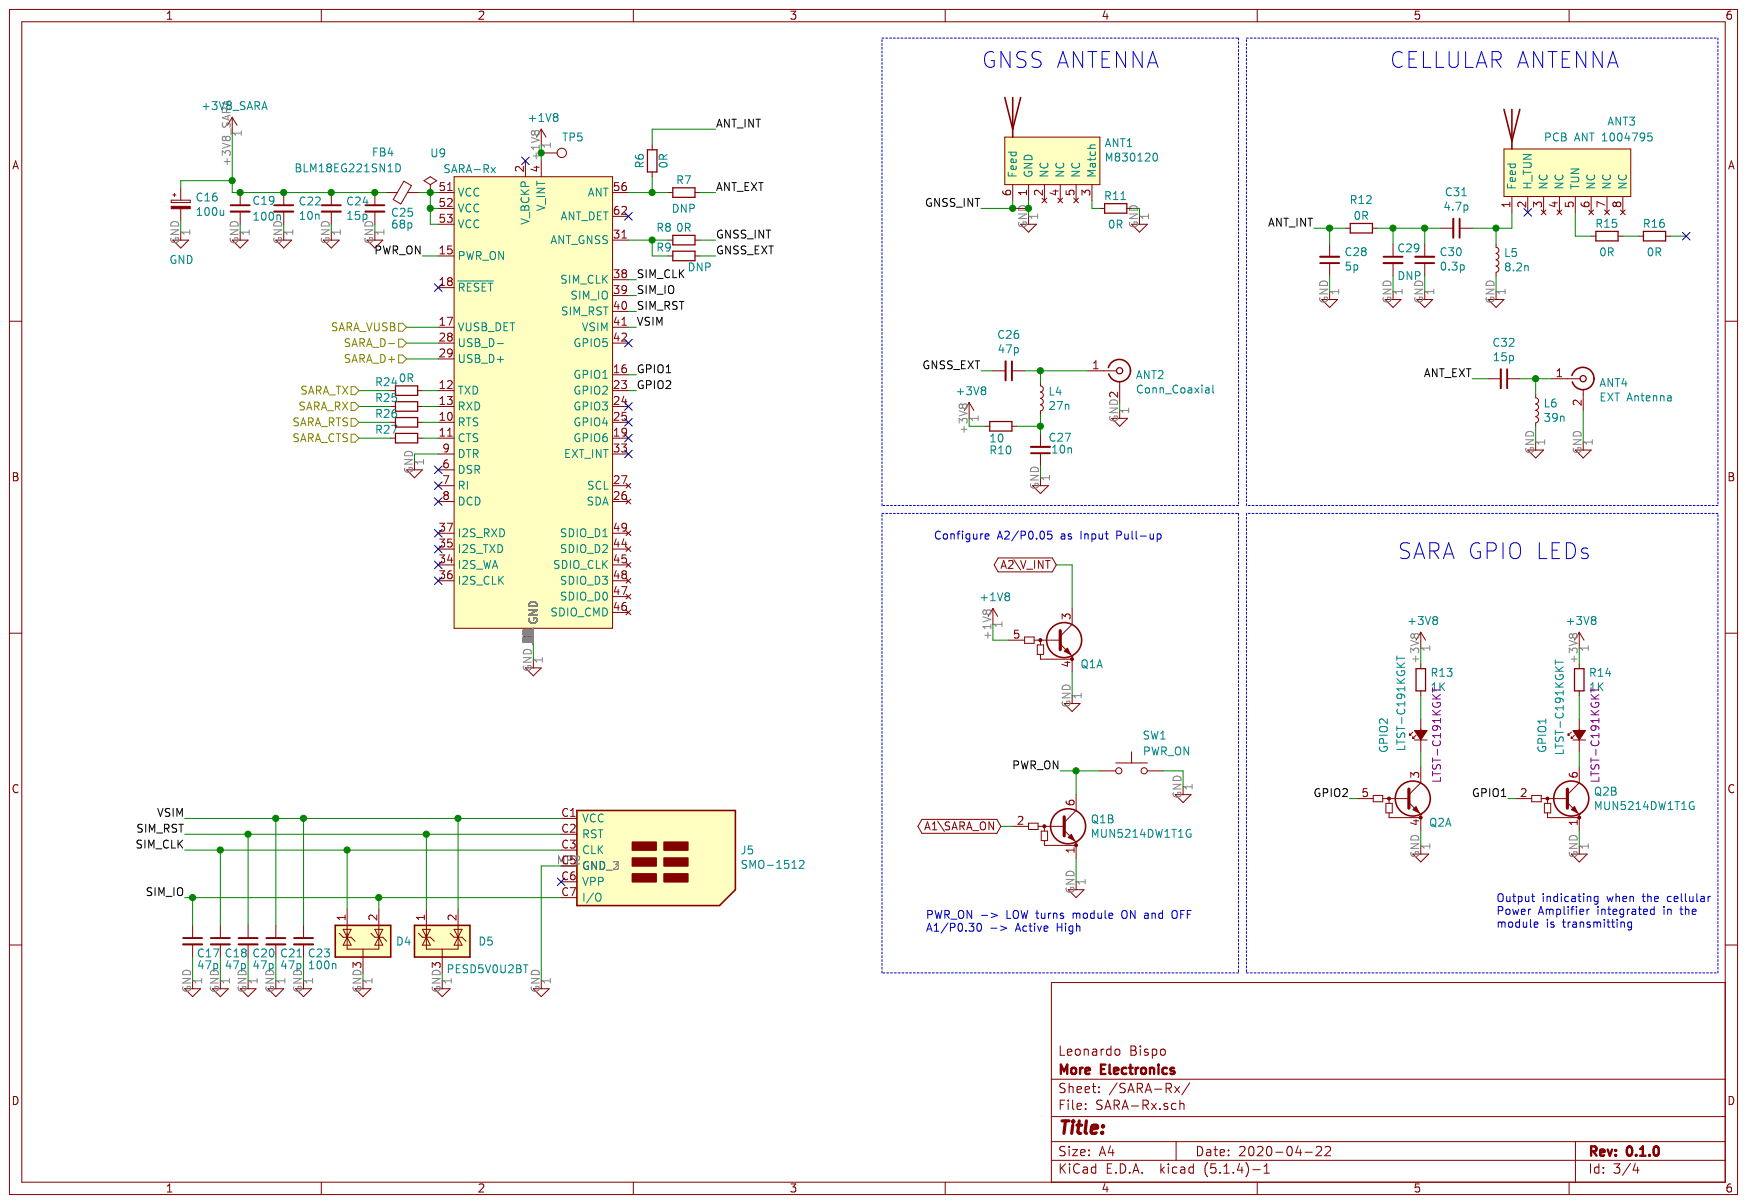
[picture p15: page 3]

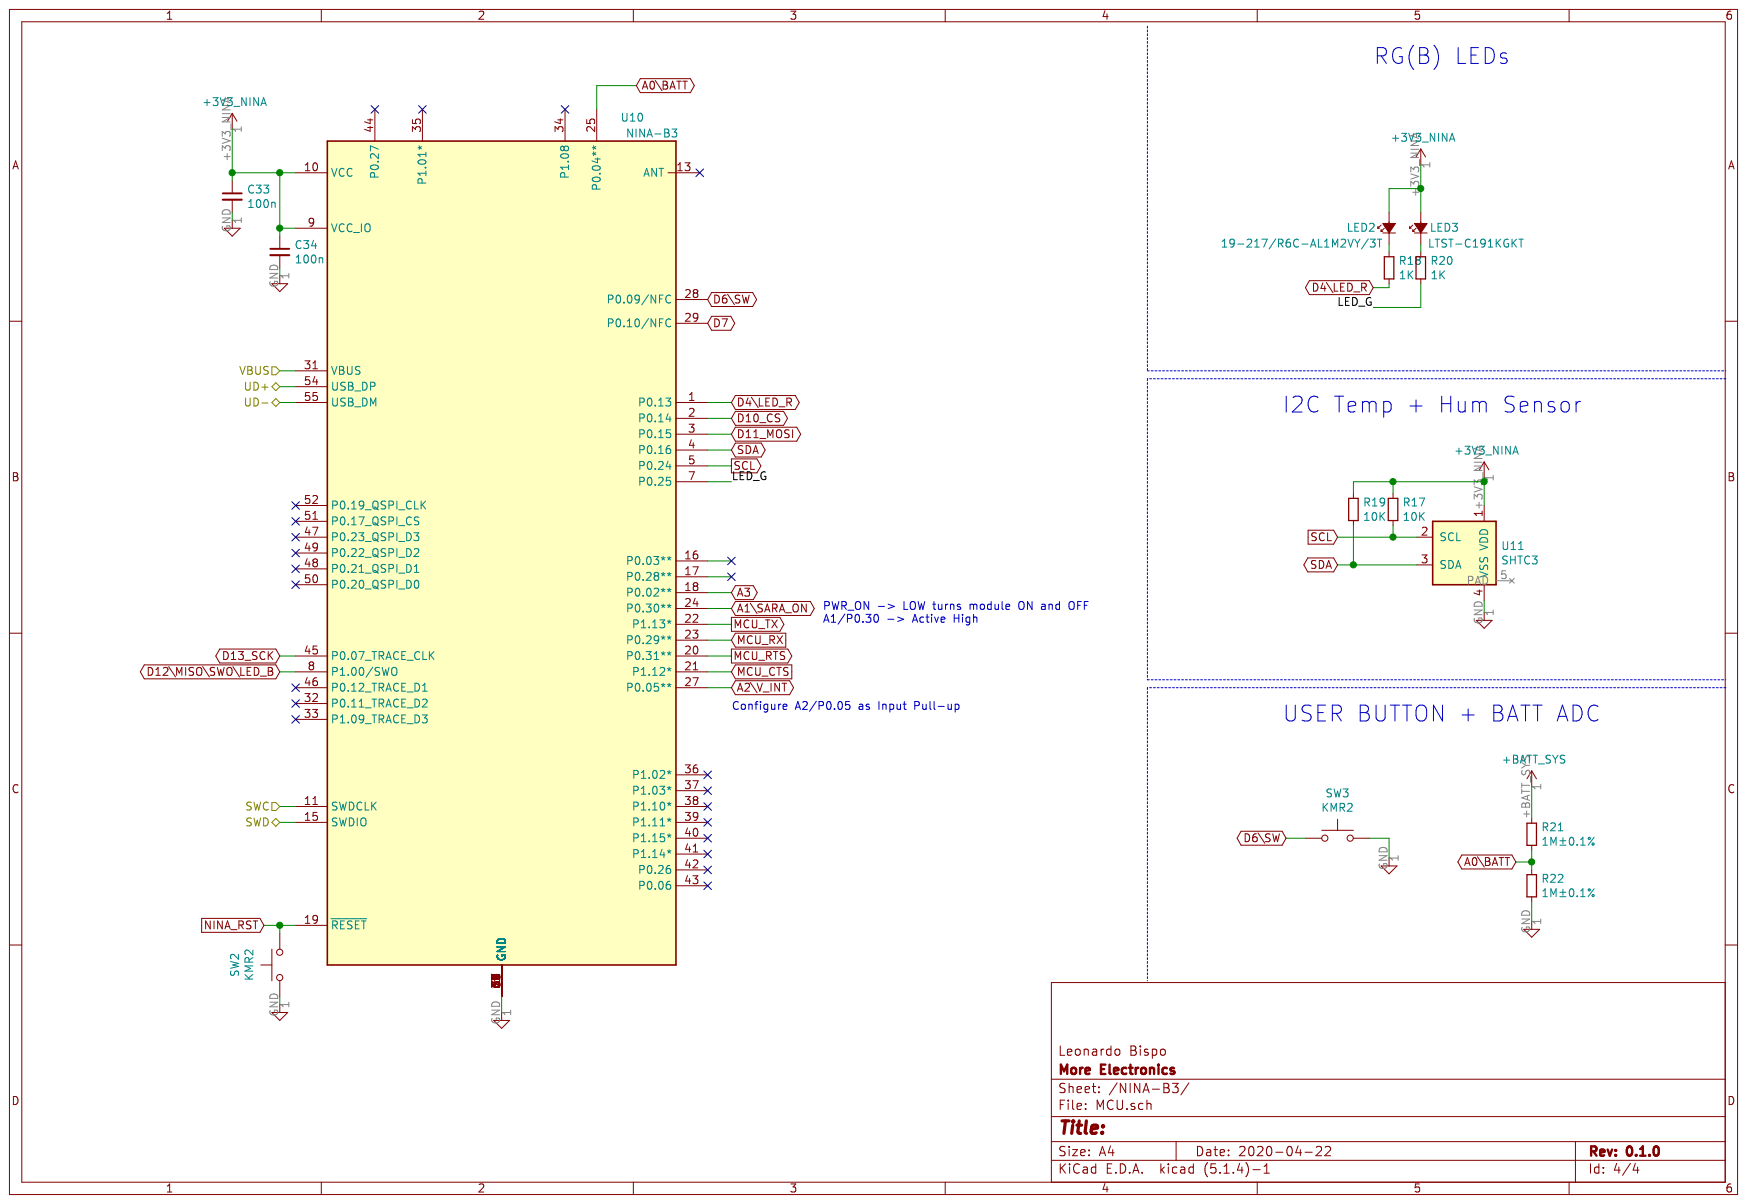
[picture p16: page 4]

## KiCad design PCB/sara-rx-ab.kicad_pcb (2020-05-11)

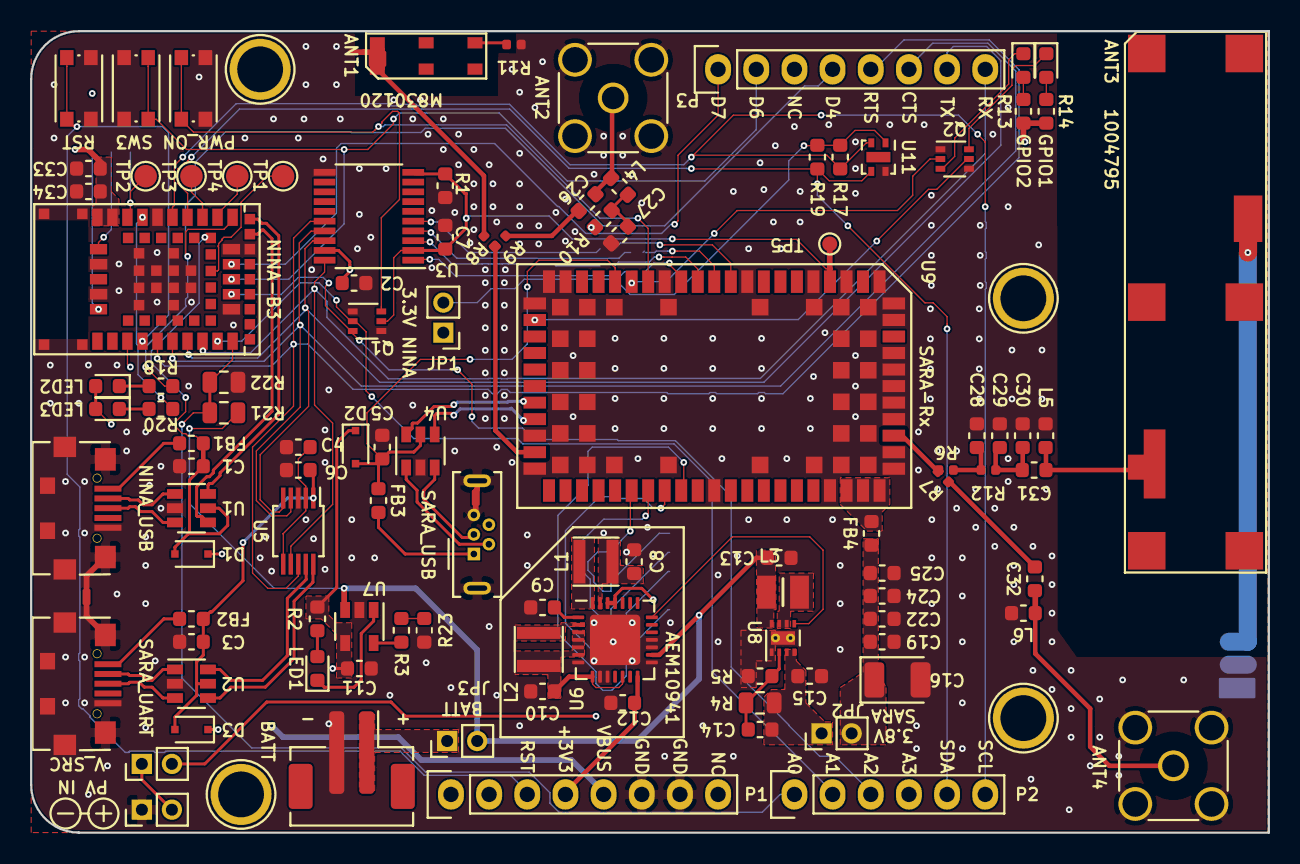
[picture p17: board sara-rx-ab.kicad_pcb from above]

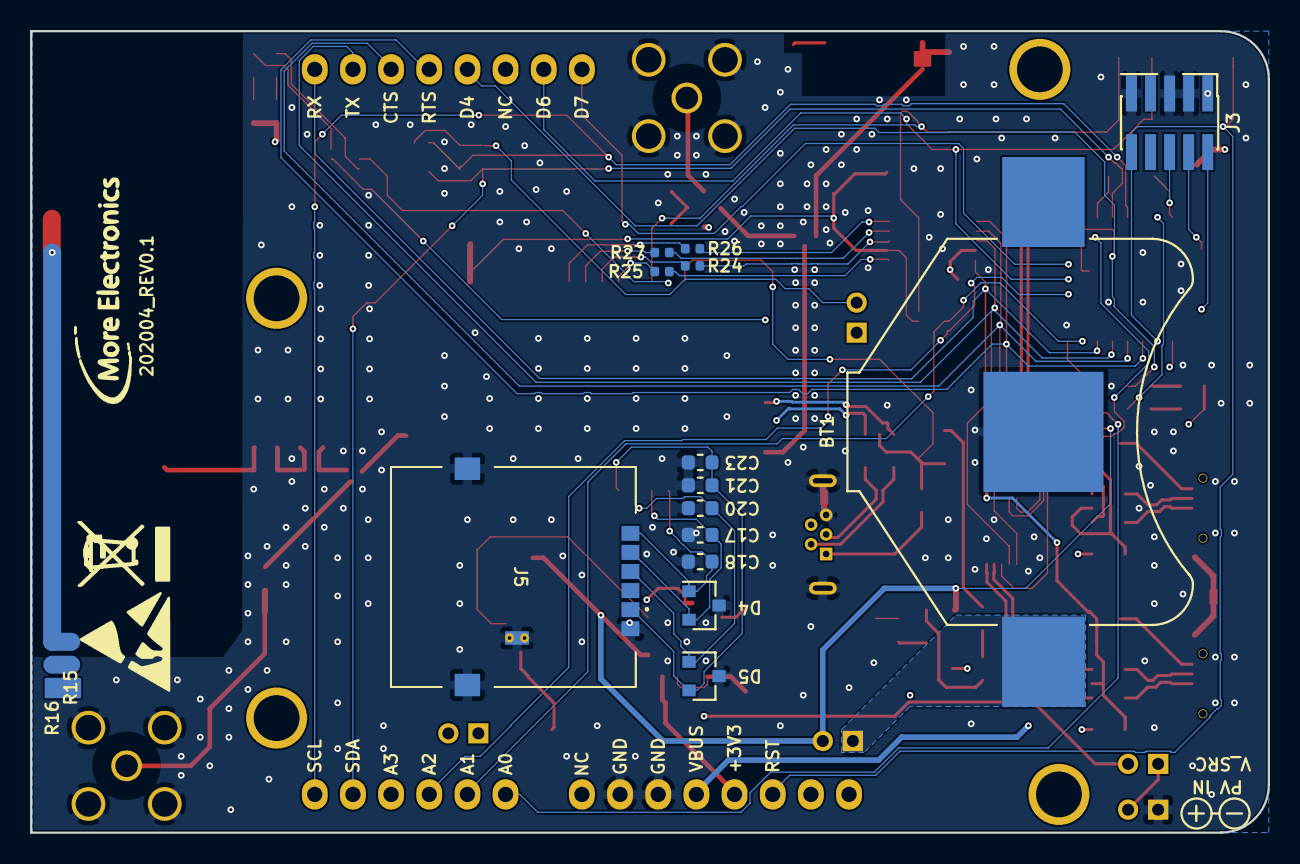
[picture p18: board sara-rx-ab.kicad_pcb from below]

Board: 4 copper layers, 82.4 x 53.3 mm, 128 parts (16 on the bottom side), 99 nets.

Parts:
ANT1: M830120
ANT2: Conn_Coaxial; SMA_Amphenol_132291_Vertical
ANT3: PCB ANT 1004795; 1009475
ANT4: EXT Antenna; SMA_Amphenol_132291_Vertical
BT1: LIR2450; BatteryHolder_Keystone_3008_1x2450
BT2: EXT BATT; JST_PH_B2B-PH-SM4-TB_1x02-1MP_P2.00mm_Vertical
C1, C2, C3, C5, C6, C7, C19, C23, C33, C34: 100n; C_0603_1608Metric
C4: 1u; C_0603_1608Metric
C8, C9, C10, C11, C12, C13, C15: 10u; C_0603_1608Metric
C14, C31: 4.7p; C_0603_1608Metric
C16: 100u; CP_EIA-3528-21_Kemet-B
C17, C18, C20, C21, C26: 47p; C_0603_1608Metric
C22, C27: 10n; C_0603_1608Metric
C24, C32: 15p; C_0603_1608Metric
C25: 68p; C_0603_1608Metric
C28: 5p; C_0603_1608Metric
C29: DNP; C_0603_1608Metric
C30: 0.3p; C_0603_1608Metric
D1, D2, D3: PMEG4010CEJ; D_SOD-323F
D4, D5: PESD5V0U2BT; SOT-23
FB1, FB2, FB3, FB4: BLM18EG221SN1D; L_0603_1608Metric
GPIO1, GPIO2: LTST-C191KGKT; LED_0603_1608Metric
J1: SOLAR PV; PinHeader_1x02_P2.00mm_Vertical
J2, J4: Bridge; 4Layer_15mil
J3: FTSH-105-01; SWD_JTAG
J5: SMO-1512; SMO1512
J6: Bridge; 4Layer_square
JP1, JP2, JP3, JP4: Jumper_NC_Small; PinHeader_1x02_P2.00mm_Vertical
L1, L2: 10u; L_Taiyo-Yuden_NRH30xx
L3: DFE252012P-R47M=P2; INDC2520X120N
L4: 27n; L_0603_1608Metric
L5: 8.2n; L_0603_1608Metric
L6: 39n; L_0603_1608Metric
LED1, LED2: 19-217/R6C-AL1M2VY/3T; LED_0603_1608Metric
LED3: LTST-C191KGKT; LED_0603_1608Metric
P1: Power; Socket_Strip_Arduino_1x08
P2: Analog; Socket_Strip_Arduino_1x06
P3: Digital; Socket_Strip_Arduino_1x08
P4, P5, P6, P7: CONN_01X01; Arduino_1pin
Q1, Q2: MUN5214DW1T1G; SOT-363_SC-70-6
R1, R2, R3, R17, R19, R23: 10K; R_0603_1608Metric
R4, R21, R22: 1M±0.1%; R_0805_2012Metric
R5: 267K; R_0603_1608Metric
R6, R8, R11, R12, R15, R16, R24, R25, R26, R27: 0R; R_0402_1005Metric
R7, R9: DNP; R_0402_1005Metric
R10: 10; R_0603_1608Metric
R13, R14, R18, R20: 1K; R_0603_1608Metric
SW1: PWR_ON; SW_Push_1P1T_NO_CK_KMR2
SW2, SW3: KMR2; SW_Push_1P1T_NO_CK_KMR2
TP1, TP2, TP3, TP4: TestPoint; TestPoint_Pad_D1.5mm
TP5: TestPoint; TestPoint_Pad_D1.0mm
U1, U2, U4: USBLC6-2SC6; SOT-23-6
U3: TXS0108EPW; TSSOP-20_4.4x6.5mm_P0.65mm
U5: HT42B534-MSOP; MSOP-10_3x3mm_P0.5mm
U6: AEM10941; QFN-28-1EP_5x5mm_P0.5mm_EP3.35x3.35mm
U7: TP4054; SOT-23-5
U8: TPS61021A; WSON-8-1EP_2x2mm_P0.5mm_EP0.9x1.6mm_ThermalVias
U9: SARA-Rx; ublox_SARA-G3_LGA-96
U10: NINA-B3
U11: SHTC3; AMS_QFN-4-1EP_2x2mm_P0.95mm_EP0.7x1.6mm
USB1: USB_B_Micro; C77238
USB2: USB_B_Micro_C77238; C77238
USB3: USB_B_Micro_C145795; USB_Micro-B_U-D-M5DD-W-1_VERTICAL

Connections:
+1V8: C7.1, Q1.5, R1.2, TP5.1, U3.2, U3.10, U9.4
+3V3: C2.1, C12.1, J3.1, JP1.1, P1.4, U3.19, U6.14
+3V3_NINA: C33.1, C34.1, JP1.2, LED2.2, LED3.2, R17.1, R19.1, U10.9, U10.10, U11.1
+3V8: C14.2, C15.2, JP2.1, R4.2, R10.2, R13.1, R14.1, U8.3, U8.4
+3V8_SARA: C16.1, C19.1, C22.1, C24.1, C25.1, FB4.1, JP2.2
+5C: C1.2, D1.2, FB1.1, U1.5, U10.31
+5F: C5.1, D2.2, FB3.1, U4.5, U9.17
+5P: C3.1, C6.2, D3.2, FB2.1, U2.5, U5.1
+BATT_SYS: C13.2, JP3.2, L3.1, R21.1, U6.16, U7.3, U8.8
+V_PV: JP4.2, U6.25, U6.26
/MCU_D+: U1.4, U10.54
/MCU_D-: U1.6, U10.55
/MCU_I_D+: U1.3, USB1.3
/MCU_I_D-: U1.1, USB1.2
/NINA-B3/LED_G: R20.2, U10.7
/NINA-B3/SWC: J3.4, U10.11
/NINA-B3/SWD: J3.2, U10.15
/POWER MGT/LDO_EN: U6.21, U8.5
/POWER MGT/VBATT: BT1.1, BT2.1, JP3.1
/POWER MGT/VBUCK: C10.1, L2.1, U6.3, U6.4, U6.5, U6.6, U6.8, U6.12
/POWER MGT/V_SRC: J1.2, JP4.1
/SARA-Rx/ANT_EXT: C32.2, R7.2
/SARA-Rx/ANT_INT: C28.2, R6.2, R12.1
/SARA-Rx/GNSS_EXT: C26.2, R9.2
/SARA-Rx/GNSS_INT: ANT1.6, J6.1, R8.2
/SARA-Rx/GPIO1: Q2.2, U9.16
/SARA-Rx/GPIO2: Q2.5, U9.23
/SARA-Rx/PWR_ON: Q1.6, SW1.1, U9.15
/SARA-Rx/SARA_CTS: R27.1, U3.4
/SARA-Rx/SARA_RTS: R26.1, U3.5
/SARA-Rx/SARA_RX: R25.1, U3.1
/SARA-Rx/SARA_TX: R24.1, U3.3
/SARA-Rx/SIM_CLK: C18.1, D4.1, J5.C3, U9.38
/SARA-Rx/SIM_IO: C17.1, D4.2, J5.C7, U9.39
/SARA-Rx/SIM_RST: C20.1, D5.1, J5.C2, U9.40
/SARA-Rx/VSIM: C21.1, C23.1, D5.2, J5.C1, U9.41
/SARA_D+: U4.4, U9.29
/SARA_D-: U4.6, U9.28
/SARA_I_D+: U4.3, USB3.3
/SARA_I_D-: U4.1, USB3.2
/UART_D+: U2.4, U5.10
/UART_D-: U2.6, U5.9
/UART_I_D+: U2.3, USB2.3
/UART_I_D-: U2.1, USB2.2
A0\BATT: P2.1, R21.2, R22.1, U10.25
A1\SARA_ON: P2.2, Q1.2, U10.24
A2\V_INT: P2.3, Q1.3, U10.27
A3: P2.4, U10.18
D4\LED_R: P3.4, R18.2, U10.1
D6\SW: P3.2, SW3.1, U10.28
D7: P3.1, U10.29
D10_CS: TP4.1, U10.2
D11_MOSI: TP3.1, U10.3
D12\MISO\SWO\LED_B: J3.6, TP2.1, U10.8
D13_SCK: TP1.1, U10.45
GND: ANT1.1, ANT2.2, ANT4.2, BT1.2, BT2.2, C1.1, C2.2, C3.2, C4.1, C5.2, C6.1, C7.2, C8.2, C9.1, C10.2, C11.2, C12.2, C13.1, C15.1, C16.2, C17.2, C18.2, C19.2, C20.2, C21.2, C22.2, C23.2, C24.2, C25.2, C27.1, C28.1, C29.2, C30.1, C33.2, C34.2, D4.3, D5.3, J1.1, J2.1, J2.2, J3.3, J3.5, J3.9, J4.1, J4.2, J5.C5, J5.MP1, J5.MP2, J6.2, L5.2, L6.2, P1.6, P1.7, Q1.1, Q1.4, Q2.1, Q2.4, R1.1, R5.1, R11.2, R22.2, R23.2, SW1.2, SW2.1, SW3.2, U1.2, U2.2, U3.11, U4.2, U5.3, U6.7, U6.9, U6.10, U6.15, U6.17, U6.18, U6.29, U7.2, U8.1, U8.9, U9.1, U9.3, U9.5, U9.9, U9.14, U9.20, U9.21, U9.22, U9.30, U9.32, U9.43, U9.50, U9.54, U9.55, U9.57, U9.58, U9.59, U9.60, U9.61, U9.63, U9.64, U9.65, U9.66, U9.67, U9.68, U9.69, U9.70, U9.71, U9.72, U9.73, U9.74, U9.75, U9.76, U9.77, U9.78, U9.79, U9.80, U9.81, U9.82, U9.83, U9.84, U9.85, U9.86, U9.87, U9.88, U9.89, U9.90, U9.91, U9.92, U9.93, U9.94, U9.95, U9.96, U10.6, U10.12, U10.14, U10.26, U10.30, U10.53, U10.56, U10.57, U10.58, U10.59, U10.60, U10.61, U10.62, U10.63, U10.64, U10.65, U10.66, U10.67, U10.68, U10.69, U10.70, U10.71, U11.4, USB1.5, USB1.6, USB1.7, USB1.8, USB1.9, USB1.10, USB2.5, USB2.6, USB2.7, USB2.8, USB2.9, USB2.10, USB3.5, USB3.6, USB3.7
MCU_CTS: P3.6, U3.17, U5.4, U10.21
MCU_RTS: P3.5, U3.16, U5.8, U10.20
MCU_RX: P3.8, U3.20, U5.7, U10.23
MCU_TX: P3.7, U3.18, U5.5, U10.22
NINA_RST: J3.10, P1.3, SW2.2, U10.19
unnamed: ANT1.3, R11.1
unnamed: ANT2.1, C26.1, L4.1
unnamed: ANT3.1, C31.1, L5.1
unnamed: ANT3.5, R15.1
unnamed: ANT4.1, C32.1, L6.1
unnamed: C4.2, U5.2, U5.6
unnamed: C8.1, L1.1, U6.27
unnamed: C9.2, U6.1
unnamed: C14.1, R4.1, R5.2, U8.2
unnamed: C27.2, L4.2, R10.1
unnamed: C29.1, C30.2, C31.2, R12.2
unnamed: FB1.2, USB1.1
unnamed: FB2.2, USB2.1
unnamed: FB3.2, USB3.1
unnamed: FB4.2, U9.51, U9.52, U9.53
unnamed: GPIO1.1, Q2.6
unnamed: GPIO1.2, R14.2
unnamed: GPIO2.1, Q2.3
unnamed: GPIO2.2, R13.2
unnamed: L1.2, U6.28
unnamed: L2.2, U6.2
unnamed: L3.2, U8.6, U8.7
unnamed: LED1.1, U7.1
unnamed: LED1.2, R2.2
unnamed: LED2.1, R18.1
unnamed: LED3.1, R20.1
unnamed: R3.1, U7.5
unnamed: R6.1, R7.1, U9.56
unnamed: R8.1, R9.1, U9.31
unnamed: R15.2, R16.1
unnamed: R3.2, R23.1
unnamed: R24.2, U9.12
unnamed: R25.2, U9.13
unnamed: R26.2, U9.10
unnamed: R27.2, U9.11
SCL: P2.6, R17.2, U10.5, U11.2
SDA: P2.5, R19.2, U10.4, U11.3
VBUS: C11.1, D1.1, D2.1, D3.1, P1.5, R2.1, U7.4

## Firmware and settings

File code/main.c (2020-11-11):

/******************************************************************************

 * u-blox Cellular IoT AT Commands Example
 * Leonardo Bispo
 * Dec, 2019
 * https://github.com/ldab/ublox_sara_nina

 * Distributed as-is; no warranty is given.

******************************************************************************/

#include <stdbool.h>
#include <stdint.h>
#include <stdio.h>

#include "boards.h"
#include "bsp.h"

#include "app_timer.h"
#include "nrf_drv_clock.h"
#include "nrf_delay.h"

#include "nrf_soc.h"
#include "nrf_pwr_mgmt.h"
#include "nordic_common.h"

#include "nrf_log.h"
#include "nrf_log_ctrl.h"
#include "nrf_log_default_backends.h"

#include "iotublox.h"
#include "mqtt.h"
#include "shtc3.h"
#include "nrf_drv_saadc.h"

#define MQTT_HOST     "io.adafruit.com"
#define MQTT_PORT     1883
#define MQTT_PORT_SSL 8883
#define MQTT_ID       "n928y23dj09u20"
#define MQTT_USER     "lbispo"
#define MQTT_PASS     "aio_hsNM78bPq2QFgWBtzWB9LkgOeA5a"  // NOTE password too long for +UMQTT

//#define MQTT_HOST     "m24.cloudmqtt.com"
//#define MQTT_PORT     17603
//#define MQTT_PORT_SSL 27603
//#define MQTT_ID       "n928y23dj09u20"
//#define MQTT_USER     "qvpgdxqg"
//#define MQTT_PASS     "YVTESIVDgHlN"

//#define MQTT_HOST     "a2jzp6o827zjxz-ats.iot.us-east-2.amazonaws.com"
//#define MQTT_PORT     17603
//#define MQTT_PORT_SSL 8883
//#define HTTP_PORT_SSL 8443
//#define MQTT_ID       "n928y23dj09u20"
//#define MQTT_USER     ""
//#define MQTT_PASS     ""

#define ADC_REF_VOLTAGE_IN_MILLIVOLTS   600                                     /**< Reference voltage (in milli volts) used by ADC while doing conversion. */
#define ADC_PRE_SCALING_COMPENSATION    6                                       /**< The ADC is configured to use VDD with 1/3 prescaling as input. And hence the result of conversion is to be multiplied by 3 to get the actual value of the battery voltage.*/
#define DIODE_FWD_VOLT_DROP_MILLIVOLTS  0//128                                      // NOTE changed to match measurement
#define ADC_RES_8BIT                    256                                     /**< Maximum digital value for 10-bit ADC conversion. */
#define ADC_RES_10BIT                   1024                                    /**< Maximum digital value for 10-bit ADC conversion. */
#define ADC_RES_14BIT                   16384                                   /**< Maximum digital value for 14-bit ADC conversion. */

#define ADC_RESULT_IN_MILLI_VOLTS(ADC_VALUE)\
        ((((ADC_VALUE) * ADC_REF_VOLTAGE_IN_MILLIVOLTS) / ADC_RES_14BIT) * ADC_PRE_SCALING_COMPENSATION * 2)  // NOTE check resolution at sdk_config.h

static nrf_saadc_value_t adc_buf;

#define SLEEP_COUNTERTIME_MS  (60 * 60 * 1000UL)
APP_TIMER_DEF(m_wake_timer_id);
volatile bool wake_evt = true;

/**@brief Function for starting RTC wake timer
 */
static void wake_on_RTC(void * p_context)
{
    UNUSED_PARAMETER(p_context);

    bsp_board_led_invert(1);

    wake_evt = true;
}

/**@brief Function for Waiting for an event / Sleep.
 */
static void sleep_handler(void)
{
    __SEV();    
    __WFE();
    __WFE();
}

/**@brief Function for configuring ADC to do battery level conversion.
 */
void saadc_event_handler(nrf_drv_saadc_evt_t const * p_event)
{
    if (p_event->type == NRF_DRV_SAADC_EVT_DONE)
    {
      // no implementation needed
    }
}

/**@brief Function for handling bsp events.
 */
void bsp_evt_handler(bsp_event_t evt)
{
    uint32_t err_code;
    switch (evt)
    {
        case BSP_EVENT_KEY_0:
            err_code = app_timer_stop(m_wake_timer_id);
            APP_ERROR_CHECK(err_code);
            wake_evt = true;
            break;

        default:
            return; // no implementation needed
    }
}

/**@brief Function for configuring ADC to do battery level conversion.
 */
static void adc_configure(void)
{
    ret_code_t err_code = nrf_drv_saadc_init(NULL, saadc_event_handler);
    APP_ERROR_CHECK(err_code);

    nrf_saadc_channel_config_t config =
        NRF_DRV_SAADC_DEFAULT_CHANNEL_CONFIG_SE(SAADC_CH_PSELP_PSELP_AnalogInput2);    // P0.04 = AnalogIn 2 -> https://infocenter.nordicsemi.com/index.jsp?topic=%2Fcom.nordic.infocenter.nrf52832.ps.v1.1%2Fpin.html

    err_code = nrf_drv_saadc_channel_init(0, &config);
    APP_ERROR_CHECK(err_code);
}

/**@brief Function for turning modem ON.
 */
bool sara_pwr_on(void)
{
    nrf_gpio_pin_write(ARDUINO_A1_PIN, 1);
    nrf_delay_ms(500);
    nrf_gpio_pin_write(ARDUINO_A1_PIN, 0);
    nrf_delay_ms(4500);

    return !nrf_gpio_pin_read(ARDUINO_A2_PIN);
}

/**@brief Function for turning modem Off.
 */
bool sara_pwr_off(void)
{
  NRF_LOG_INFO("Turning SARA off");

  if( nrf_gpio_pin_read(ARDUINO_A2_PIN) == 0 )
  {
    nrf_gpio_pin_write(ARDUINO_A1_PIN, 1);
    nrf_delay_ms(1500);                   //TODO remove delay and attach interrupt to ARDUIONO A1 PIN
    nrf_gpio_pin_write(ARDUINO_A1_PIN, 0);
  }
  else
  {
    // already off
  }

  return true;
}

/**@brief Function for putting NINA to sleep.
 */
bool nina_sleep(uint32_t sleep_time)
{
  bsp_indication_set(BSP_INDICATE_USER_STATE_1);

  sara_pwr_off();

  nrf_libuarte_async_uninit(&modem_uart);

  // work around for UARTE uninit does not end DMA: https://devzone.nordicsemi.com/f/nordic-q-a/54271/nrf52840-fails-to-go-to-low-power-mode-when-using-uart-rx-double-buffering
  *(volatile uint32_t *)0x40002FFC = 0;
  *(volatile uint32_t *)0x40002FFC;
  *(volatile uint32_t *)0x40002FFC = 1;

  nrf_gpio_cfg_default(TX_PIN_NUMBER);
  nrf_gpio_cfg_default(RX_PIN_NUMBER);

  bsp_indication_set(BSP_INDICATE_IDLE);

  ret_code_t err_code = app_timer_create(&m_wake_timer_id, APP_TIMER_MODE_SINGLE_SHOT, wake_on_RTC);
  APP_ERROR_CHECK(err_code);

  err_code = app_timer_start(m_wake_timer_id, APP_TIMER_TICKS(sleep_time), NULL);
  APP_ERROR_CHECK(err_code);

  wake_evt = false;
}

void read_sensor_adc(float *temp, float *humi, uint16_t *batt_v, uint8_t *batt_pc)
{
  float _t;
  float _h;

  ret_code_t err_code = SHTC3_GetTempAndHumiPolling(&_t, &_h);
  APP_ERROR_CHECK(err_code);

  err_code = SHTC3_Sleep();
  APP_ERROR_CHECK(err_code);

  *temp = _t;
  *humi = _h;

  nrf_saadc_value_t adc_result;
  err_code = nrf_drv_saadc_sample_convert(0, &adc_result);
  APP_ERROR_CHECK(err_code);

  *batt_v  = ADC_RESULT_IN_MILLI_VOLTS(adc_result) + DIODE_FWD_VOLT_DROP_MILLIVOLTS;
  *batt_pc = battery_level_in_percent((uint16_t)(*batt_v * 3000 / 4100));

  NRF_LOG_INFO("Temp: " NRF_LOG_FLOAT_MARKER "degC and Hum: " NRF_LOG_FLOAT_MARKER "%%", NRF_LOG_FLOAT(_t), NRF_LOG_FLOAT(_h)); NRF_LOG_FLUSH();
  NRF_LOG_INFO("ADC: %d, Milli %d, Perc %d", adc_result, *batt_v, *batt_pc); NRF_LOG_FLUSH();
}

/**
 * @brief Function for main application entry.
 */
int main(void)
{
    ret_code_t err_code = NRF_LOG_INIT(app_timer_cnt_get);    // Start RTT with timestamps
    APP_ERROR_CHECK(err_code);

    NRF_LOG_DEFAULT_BACKENDS_INIT();

    err_code = bsp_init(BSP_INIT_LEDS | BSP_INIT_BUTTONS, bsp_evt_handler);

    APP_ERROR_CHECK(err_code);

    nrf_gpio_cfg_input(ARDUINO_A2_PIN, NRF_GPIO_PIN_PULLUP);  // V_INT input
    nrf_gpio_cfg_output(ARDUINO_A1_PIN);                      // PWR_ON Pin, active High
    nrf_gpio_cfg_output(RTS_PIN_NUMBER);

    // Function starting the internal low-frequency clock LFCLK XTAL oscillator.
    // (When SoftDevice is enabled the LFCLK is always running and this is not needed).
    err_code = nrf_drv_clock_init();
    APP_ERROR_CHECK(err_code);
    nrf_drv_clock_lfclk_request(NULL);

    err_code = app_timer_init();
    APP_ERROR_CHECK(err_code);

    bsp_indication_set(BSP_INDICATE_ADVERTISING_SLOW);
/*
    while( nrf_gpio_pin_read(BUTTON_1) )
    {
      sleep_handler();//__WFE();
    }
*/
    bsp_indication_set(BSP_INDICATE_ADVERTISING);

    adc_configure();
    twi_init();
       
    float    temperature; // temperature
    float    humidity;    // relative humidity
    uint16_t batt_lvl_in_milli_volts;
    uint8_t  batt_lvl_in_percentage;

    while (true)
    {        
        if( /*!nrf_gpio_pin_read(BUTTON_1)*/ wake_evt == true )
        {

        read_sensor_adc(&temperature, &humidity, &batt_lvl_in_milli_volts, &batt_lvl_in_percentage);

        sara_pwr_on();

        uart_init();

        // INIT Modem
        iotublox_init(100, "7", 524420, 524420);
        iotublox_powerSave(false, false, NULL, NULL);
        if( iotublox_connect("lpwa.telia.iot") == false )
          goto FINISH;
        
        iot_closeSocket( 0 );
        uart_clear();

        char _msg[128];

        /***************************** POST Secure Example using AT Commands API*****************************************/
        #ifdef HTTP_PORT_SSL
          do{
            iot_connSocketSSL(MQTT_HOST, HTTP_PORT_SSL, AWS_CERTS[0], AWS_CERTS[1], AWS_CERTS[2]);
            }while(socket.connected == false);

          char post_content[] = "{ \"message\": \"Hello, world\" }";
          char POST[1024] = "";
          sprintf(POST, "POST /topics/nina/test HTTP/1.1\nHost: %s:%d\nUser-Agent: Arduino/1.0\nContent-Type: application/x-www-form-urlencoded\nContent-Length: %d\n\n%s\n\n", MQTT_HOST, HTTP_PORT_SSL, strlen(post_content), post_content);
          iot_write(POST, strlen(POST));
          iot_readSocket();

          //char* response = strstr(socket.content, "\r\n\r\n") + 4;       // Filter HTTP response

          NRF_LOG_INFO("Respons -> %s", socket.content);
          NRF_LOG_FLUSH();

          iot_closeSocket(socket.identifier);
        #endif
          /***********************************************************************************************************/

          /*****************************MQTT Non-Secure using AT Commands API*****************************************/
          /*
          bsp_indication_set(BSP_INDICATE_ADVERTISING_WHITELIST);

          sprintf(_msg, "{\"T\":%.01f,\"H\":%.01f,\"B\":%d,\"RSRP\":%.02f,\"Type\": \"Non Sec API\"}", temperature, humidity, batt_lvl_in_percentage, modemInfo.RSRP);
          iotublox_mqtt_config(MQTT_HOST, MQTT_PORT, MQTT_ID, MQTT_USER, MQTT_PASS);
          iotublox_mqtt_publish("nina/test", _msg, 0);
          iotublox_mqtt_disconnect();
          */
          //nrf_delay_ms(1000);
          /***********************************************************************************************************/

          /*****************************MQTT Non-Secure Socket implementation*****************************************/
          bsp_indication_set(BSP_INDICATE_ADVERTISING_DIRECTED);

          do{
            iot_connSocket(MQTT_HOST, MQTT_PORT);
            }while(socket.connected == false);

          float _b = (float)batt_lvl_in_milli_volts / 1000.0f;
          char  topic[32];

          memset(_msg, '\0', sizeof(_msg));
          sprintf(_msg, "{\"feeds\": {\"T\": %.01f,\"H\": %.01f,\"Bpc\": %d,\"RSRP\": %.02f,\"Bv\": %.02f}}",
                  temperature, humidity, batt_lvl_in_percentage, modemInfo.RSRP, _b);

          sprintf(topic, "lbispo/g/nina_%X/json", NRF_FICR->DEVICEADDR[0]);

          mqtt_connect(MQTT_ID, MQTT_USER, MQTT_PASS, 0, 0, 0, 0, 1);
          mqtt_publish(topic, _msg, false);
          /***********************************************************************************************************/

          //nrf_delay_ms(1000);

        /*****************************MQTT Secure Socket implementation*****************************************/
          /*
          bsp_indication_set(BSP_INDICATE_BONDING);

          do{
            iot_connSocketSSL(MQTT_HOST, MQTT_PORT_SSL, CloudMQTT_CERTS[0], CloudMQTT_CERTS[1], CloudMQTT_CERTS[2]);
            //iot_connSocketSSL(MQTT_HOST, MQTT_PORT_SSL, AWS_CERTS[0], AWS_CERTS[1], AWS_CERTS[2]);
            }while(socket.connected == false);

          memset(_msg, '\0', sizeof(_msg));
          sprintf(_msg, "{\"feeds\": {\"T\": %.01f,\"H\": %.01f,\"B\": %d,\"RSRP\": %.02f,\"Type\": \"Sec Socket\"}}", temperature, humidity, batt_lvl_in_percentage, modemInfo.RSRP);

          mqtt_connect(MQTT_ID, MQTT_USER, MQTT_PASS, 0, 0, 0, 0, true);
          mqtt_publish("lbispo/g/nina_sec/json", _msg, false);
          */
       /***********************************************************************************************************/

          FINISH: nina_sleep( SLEEP_COUNTERTIME_MS );

          NRF_LOG_FLUSH();
        }
      
        sleep_handler();
    }

}
//##END

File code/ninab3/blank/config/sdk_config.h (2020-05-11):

/**
 * Copyright (c) 2017 - 2019, Nordic Semiconductor ASA
 *
 * All rights reserved.
 *
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
 * 3. Neither the name of Nordic Semiconductor ASA nor the names of its
 *    contributors may be used to endorse or promote products derived from this
 *    software without specific prior written permission.
 *
 * 4. This software, with or without modification, must only be used with a
 *    Nordic Semiconductor ASA integrated circuit.
 *
 * 5. Any software provided in binary form under this license must not be reverse
 *    engineered, decompiled, modified and/or disassembled.
 *
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
 */



#ifndef SDK_CONFIG_H
#define SDK_CONFIG_H
// <<< Use Configuration Wizard in Context Menu >>>\n
#ifdef USE_APP_CONFIG
#include "app_config.h"
#endif
// <h> nRF_Drivers 

//==========================================================
// <e> NRFX_CLOCK_ENABLED - nrfx_clock - CLOCK peripheral driver
//==========================================================
#ifndef NRFX_CLOCK_ENABLED
#define NRFX_CLOCK_ENABLED 1
#endif
// <o> NRFX_CLOCK_CONFIG_LF_SRC  - LF Clock Source
 
// <0=> RC 
// <1=> XTAL 
// <2=> Synth 
// <131073=> External Low Swing 
// <196609=> External Full Swing 

#ifndef NRFX_CLOCK_CONFIG_LF_SRC
#define NRFX_CLOCK_CONFIG_LF_SRC 1
#endif

// <o> NRFX_CLOCK_CONFIG_IRQ_PRIORITY  - Interrupt priority
 
// <0=> 0 (highest) 
// <1=> 1 
// <2=> 2 
// <3=> 3 
// <4=> 4 
// <5=> 5 
// <6=> 6 
// <7=> 7 

#ifndef NRFX_CLOCK_CONFIG_IRQ_PRIORITY
#define NRFX_CLOCK_CONFIG_IRQ_PRIORITY 6
#endif

// <e> NRFX_CLOCK_CONFIG_LOG_ENABLED - Enables logging in the module.
//==========================================================
#ifndef NRFX_CLOCK_CONFIG_LOG_ENABLED
#define NRFX_CLOCK_CONFIG_LOG_ENABLED 0
#endif
// <o> NRFX_CLOCK_CONFIG_LOG_LEVEL  - Default Severity level
 
// <0=> Off 
// <1=> Error 
// <2=> Warning 
// <3=> Info 
// <4=> Debug 

#ifndef NRFX_CLOCK_CONFIG_LOG_LEVEL
#define NRFX_CLOCK_CONFIG_LOG_LEVEL 3
#endif

// <o> NRFX_CLOCK_CONFIG_INFO_COLOR  - ANSI escape code prefix.
 
// <0=> Default 
// <1=> Black 
// <2=> Red 
// <3=> Green 
// <4=> Yellow 
// <5=> Blue 
// <6=> Magenta 
// <7=> Cyan 
// <8=> White 

#ifndef NRFX_CLOCK_CONFIG_INFO_COLOR
#define NRFX_CLOCK_CONFIG_INFO_COLOR 0
#endif

// <o> NRFX_CLOCK_CONFIG_DEBUG_COLOR  - ANSI escape code prefix.
 
// <0=> Default 
// <1=> Black 
// <2=> Red 
// <3=> Green 
// <4=> Yellow 
// <5=> Blue 
// <6=> Magenta 
// <7=> Cyan 
// <8=> White 

#ifndef NRFX_CLOCK_CONFIG_DEBUG_COLOR
#define NRFX_CLOCK_CONFIG_DEBUG_COLOR 0
#endif

// </e>

// </e>

// <e> NRFX_PPI_ENABLED - nrfx_ppi - PPI peripheral allocator
//==========================================================
#ifndef NRFX_PPI_ENABLED
#define NRFX_PPI_ENABLED 1
#endif
// <e> NRFX_PPI_CONFIG_LOG_ENABLED - Enables logging in the module.
//==========================================================
#ifndef NRFX_PPI_CONFIG_LOG_ENABLED
#define NRFX_PPI_CONFIG_LOG_ENABLED 0
#endif
// <o> NRFX_PPI_CONFIG_LOG_LEVEL  - Default Severity level
 
// <0=> Off 
// <1=> Error 
// <2=> Warning 
// <3=> Info 
// <4=> Debug 

#ifndef NRFX_PPI_CONFIG_LOG_LEVEL
#define NRFX_PPI_CONFIG_LOG_LEVEL 3
#endif

// <o> NRFX_PPI_CONFIG_INFO_COLOR  - ANSI escape code prefix.
 
// <0=> Default 
// <1=> Black 
// <2=> Red 
// <3=> Green 
// <4=> Yellow 
// <5=> Blue 
// <6=> Magenta 
// <7=> Cyan 
// <8=> White 

#ifndef NRFX_PPI_CONFIG_INFO_COLOR
#define NRFX_PPI_CONFIG_INFO_COLOR 0
#endif

// <o> NRFX_PPI_CONFIG_DEBUG_COLOR  - ANSI escape code prefix.
 
// <0=> Default 
// <1=> Black 
// <2=> Red 
// <3=> Green 
// <4=> Yellow 
// <5=> Blue 
// <6=> Magenta 
// <7=> Cyan 
// <8=> White 

#ifndef NRFX_PPI_CONFIG_DEBUG_COLOR
#define NRFX_PPI_CONFIG_DEBUG_COLOR 0
#endif

// </e>

// </e>

// <e> NRFX_RTC_ENABLED - nrfx_rtc - RTC peripheral driver
//==========================================================
#ifndef NRFX_RTC_ENABLED
#define NRFX_RTC_ENABLED 1
#endif
// <q> NRFX_RTC0_ENABLED  - Enable RTC0 instance
 

#ifndef NRFX_RTC0_ENABLED
#define NRFX_RTC0_ENABLED 1
#endif

// <q> NRFX_RTC1_ENABLED  - Enable RTC1 instance
 

#ifndef NRFX_RTC1_ENABLED
#define NRFX_RTC1_ENABLED 0
#endif

// <q> NRFX_RTC2_ENABLED  - Enable RTC2 instance
 

#ifndef NRFX_RTC2_ENABLED
#define NRFX_RTC2_ENABLED 0
#endif

// <o> NRFX_RTC_MAXIMUM_LATENCY_US - Maximum possible time[us] in highest priority interrupt 
#ifndef NRFX_RTC_MAXIMUM_LATENCY_US
#define NRFX_RTC_MAXIMUM_LATENCY_US 2000
#endif

// <o> NRFX_RTC_DEFAULT_CONFIG_FREQUENCY - Frequency  <16-32768> 


#ifndef NRFX_RTC_DEFAULT_CONFIG_FREQUENCY
#define NRFX_RTC_DEFAULT_CONFIG_FREQUENCY 32768
#endif

// <q> NRFX_RTC_DEFAULT_CONFIG_RELIABLE  - Ensures safe compare event triggering
 

#ifndef NRFX_RTC_DEFAULT_CONFIG_RELIABLE
#define NRFX_RTC_DEFAULT_CONFIG_RELIABLE 0
#endif

// <o> NRFX_RTC_DEFAULT_CONFIG_IRQ_PRIORITY  - Interrupt priority
 
// <0=> 0 (highest) 
// <1=> 1 
// <2=> 2 
// <3=> 3 
// <4=> 4 
// <5=> 5 
// <6=> 6 
// <7=> 7
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

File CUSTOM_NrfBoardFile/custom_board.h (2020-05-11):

#ifndef CUSTOM_BOARD_H
#define CUSTOM_BOARD_H

#ifdef __cplusplus
extern "C" {
#endif

#include "nrf_gpio.h"

// In this file PIN25 is used as button SWITCH_1, if the GREEN led
// should be used it is possible to defined that one instead.
#define LEDS_NUMBER    2

#define LED_R          NRF_GPIO_PIN_MAP(0,13)   // RED -> ARDUINO_4_PIN
#define LED_G          NRF_GPIO_PIN_MAP(0,25)   // GREEN

#define LEDS_ACTIVE_STATE 0

#define LEDS_LIST { LED_R, LED_G }

#define LEDS_INV_MASK  LEDS_MASK

#define BSP_LED_0      LED_R
#define BSP_LED_1      LED_G

#define BUTTONS_NUMBER 1

//#define BUTTON_1       25  // SWITCH_1
//#define BUTTON_2       2   // SWITCH_2
#define BUTTON_1       NRF_GPIO_PIN_MAP(0, 9)
#define BUTTON_PULL    NRF_GPIO_PIN_PULLUP

#define BUTTONS_ACTIVE_STATE 0

#define BUTTONS_LIST { BUTTON_1 }

#define BSP_BUTTON_0   BUTTON_1
//#define BSP_BUTTON_1   BUTTON_2

#define RX_PIN_NUMBER  NRF_GPIO_PIN_MAP(0,29)
#define TX_PIN_NUMBER  NRF_GPIO_PIN_MAP(1,13)
#define CTS_PIN_NUMBER NRF_GPIO_PIN_MAP(1,12)
#define RTS_PIN_NUMBER NRF_GPIO_PIN_MAP(0,31)
#define HWFC           false

#define BSP_QSPI_SCK_PIN   19
#define BSP_QSPI_CSN_PIN   17
#define BSP_QSPI_IO0_PIN   20
#define BSP_QSPI_IO1_PIN   21
#define BSP_QSPI_IO2_PIN   22
#define BSP_QSPI_IO3_PIN   23

// Arduino board mappings
#define ARDUINO_SCL_PIN             24  // SCL signal pin
#define ARDUINO_SDA_PIN             16  // SDA signal pin

#define ARDUINO_13_PIN              NRF_GPIO_PIN_MAP(0, 7)  //SCK
#define ARDUINO_12_PIN              NRF_GPIO_PIN_MAP(0, 2)  //MISO
#define ARDUINO_11_PIN              NRF_GPIO_PIN_MAP(0, 15) //MOSI
#define ARDUINO_10_PIN              NRF_GPIO_PIN_MAP(0, 14) //CS
//#define ARDUINO_9_PIN               NRF_GPIO_PIN_MAP(0, 12) // HARD ACCESS PIN
//#define ARDUINO_8_PIN               NRF_GPIO_PIN_MAP(1, 9) // HARD ACCESS PIN

#define ARDUINO_7_PIN               NRF_GPIO_PIN_MAP(0, 10)
#define ARDUINO_6_PIN               NRF_GPIO_PIN_MAP(0, 9)
//#define ARDUINO_5_PIN               NRF_GPIO_PIN_MAP(0, 11) // HARD ACCESS PIN
#define ARDUINO_4_PIN               NRF_GPIO_PIN_MAP(0, 13) // RED LED
#define ARDUINO_3_PIN               RTS_PIN_NUMBER
#define ARDUINO_2_PIN               CTS_PIN_NUMBER
#define ARDUINO_1_PIN               TX_PIN_NUMBER
#define ARDUINO_0_PIN               RX_PIN_NUMBER // Digital pin 0

#define ARDUINO_A0_PIN              NRF_GPIO_PIN_MAP(0, 4)
#define ARDUINO_A1_PIN              NRF_GPIO_PIN_MAP(0, 30)
#define ARDUINO_A2_PIN              NRF_GPIO_PIN_MAP(0, 5)
#define ARDUINO_A3_PIN              NRF_GPIO_PIN_MAP(0, 2)
#define ARDUINO_A4_PIN              ARDUINO_SDA_PIN//NRF_GPIO_PIN_MAP(0, 28)
#define ARDUINO_A5_PIN              ARDUINO_SCL_PIN//NRF_GPIO_PIN_MAP(0, 3)

#ifdef __cplusplus
}
#endif

#endif // NINA_B3_H

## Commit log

2019-12-06 fix timestamp and millis
    [main.c, sdk_config.h]
2019-12-08 write/read socket implementation
2019-12-18 mqtt publish + SSL
    [SARA-Rx.sch, sara-rx-ab.kicad_pcb, sara-rx-ab.sch]
2020-01-22 PCB rel
    [AEM10941.sch, Energy budget.xlsx, MCU.sch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]
2020-04-08 i2c and SHTC3 Implementation
2020-04-08 test LEDs and Button
2020-04-09 update board dependancy
2020-04-22 PCB Rev0.1.0 Fix level shifter and silk
    [AEM10941.sch, MCU.sch, SARA-Rx.sch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]
2020-05-04 UARTE low current
2020-05-11 DMA FIX and RTC
    [main.c, sdk_config.h]
2020-05-11 Dev merge (#1)
    * dev checkpoint
    * mqtt_not_tested
    * mqtt publish + SSL
    * mqtt publish + SSL
    * PCB rel
    * i2c and SHTC3 Implementation
    * test LEDs and Button
    * update board dependancy
    * PCB Rev0.1.0 Fix level shifter and silk
    * UARTE low current
    * All on RTC1 and Low Clock (sdk.config)
    * DMA FIX and RTC
    [AEM10941.sch, Energy budget.xlsx, MCU.sch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]
2020-05-17 initial release
    [BOM.xlsx]
2020-11-04 new current readings
2020-11-04 sleep current
2020-11-11 epishine power prof

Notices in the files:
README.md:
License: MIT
